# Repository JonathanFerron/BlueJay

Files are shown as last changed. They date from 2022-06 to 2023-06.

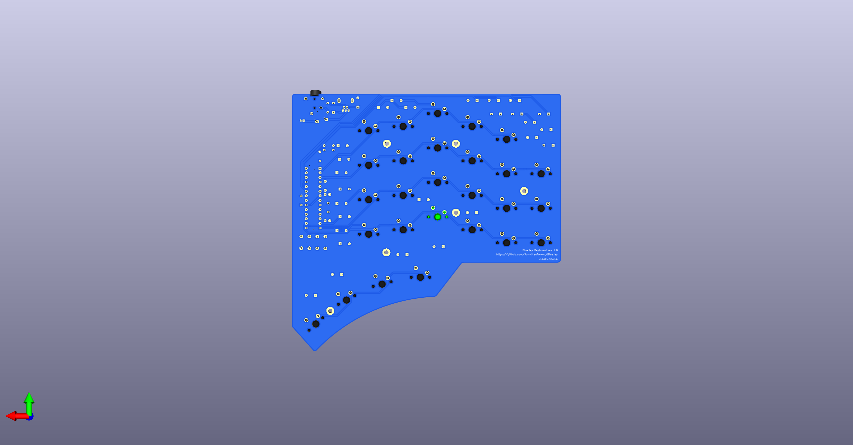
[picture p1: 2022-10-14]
printouts/bluejay_left_3D_back.png

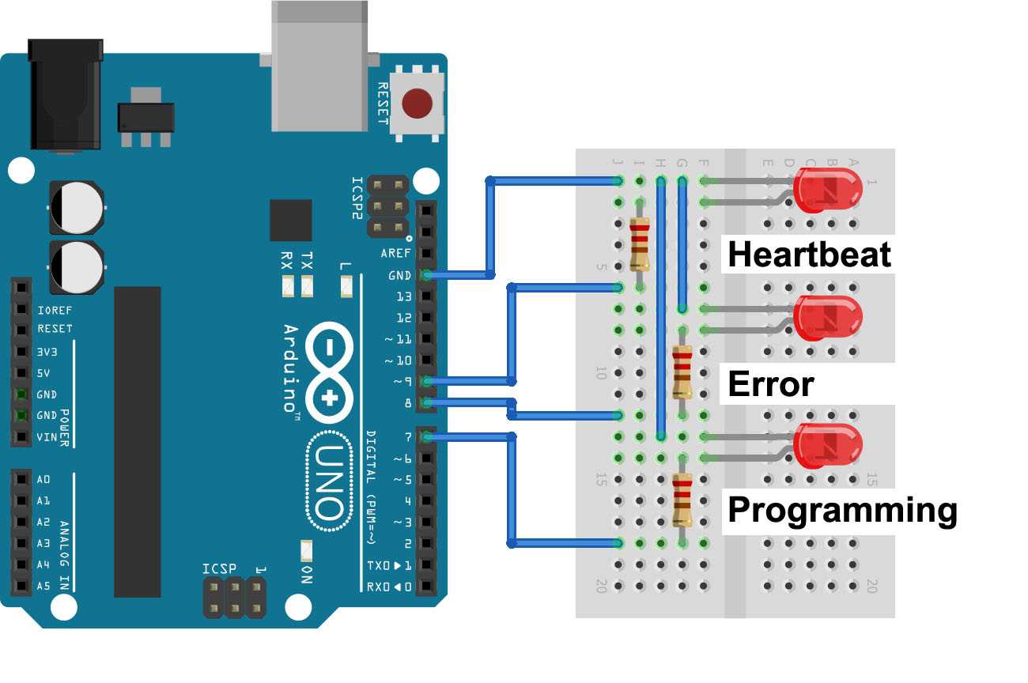
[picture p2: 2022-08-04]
build/Arduino_ISP_LEDSOK.jpg

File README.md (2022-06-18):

# BlueJay
 Split Ergonomic Keyboard

This is a project for a new split ergonomic QMK-powered keyboard. The goal is for it to be minimalist, meant for users who strictly touch-type, and made with easy to solder through-hole components. It is significantly inspired on the [Torn](https://github.com/rtitmuss/torn) split keyboard, with modifications such as adding a partial "numrow" and moving the thumb cluster further out.

Prototype Key Positions

This work is licensed under a
[Creative Commons Attribution-NonCommercial-ShareAlike 4.0 International License][cc-by-nc-sa].

[][cc-by-nc-sa]

[cc-by-nc-sa]: http://creativecommons.org/licenses/by-nc-sa/4.0/
[cc-by-nc-sa-image]: https://licensebuttons.net/l/by-nc-sa/4.0/88x31.png
[cc-by-nc-sa-shield]: https://img.shields.io/badge/License-CC%20BY--NC--SA%204.0-lightgrey.svg

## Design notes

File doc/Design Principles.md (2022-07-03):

# BlueJay54 design principles

- 6 columns, 5 rows in total (of which one is thumb cluster): 5 top row + 3x6 middle + 4 thumb cluster per hand: total of 54 keys
	+ All 1U keys:
	+ 10 x R1 top (number) row
	+ 12 x R2 qwerty row
	+ 10 x R3 home row + 2 R3 homing keys
	+ 12 x R4 bottom row
	+ 8 x R2 thumb keys (get an extra set of 8 R1 keys as well)
	+ = Total 54 keycaps

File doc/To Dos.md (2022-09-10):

# BlueJay54 To Dos

- [ ] Update Gerber Files
- [ ] Check keyboard QMK matrix.c scanning code and create default keymap.c

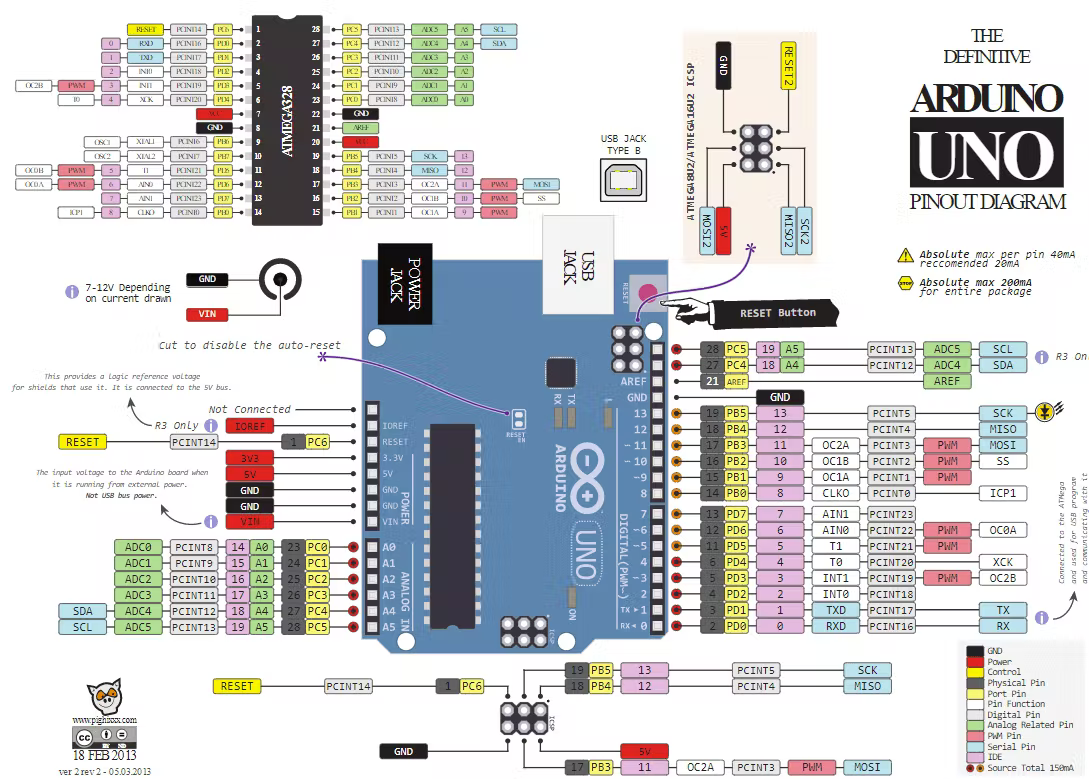
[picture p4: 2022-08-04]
build/arduino uno pinout.png

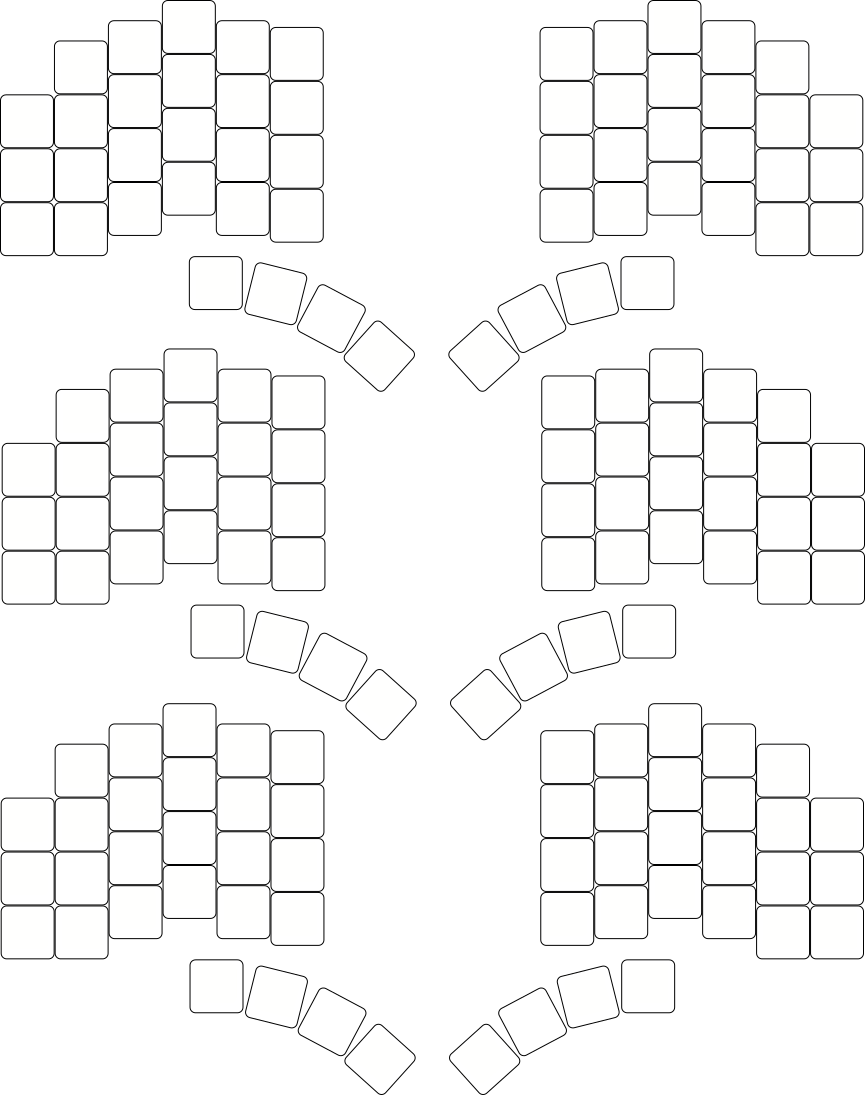
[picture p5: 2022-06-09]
doc/bluejay-prototype-v4---both-hands.png

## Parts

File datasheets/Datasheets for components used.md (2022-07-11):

- [ATMega 328P](https://www.microchip.com/en-us/product/ATmega328P)
- [MCP23017 Datasheet](https://www.microchip.com/en-us/product/mcp23017)
- [SJ-43514](https://www.cuidevices.com/product/resource/sj-4351x.pdf)
- [4.7uF Electrolytic Capacitor ECE-A1EKS4R7](https://industrial.panasonic.com/cdbs/www-data/pdf/RDF0000/ABA0000C1059.pdf)
- [Bourns Resettable Fuse MF-R010](https://www.bourns.com/docs/product-datasheets/mf-r.pdf?sfvrsn=bc732717_46)
- [Molex 548190519 Mini USB receptacle](https://www.molex.com/pdm_docs/sd/548190519_sd.pdf)

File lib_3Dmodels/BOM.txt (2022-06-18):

3DX_CUI_DEVICES_Supplier: CUI Devices
3DX_CUI_DEVICES_Description: 3.5 mm, Stereo, Right Angle, Through Hole, 4 Conductors, 0 Internal Switches, Audio Jack Connector
3DX_CUI_DEVICES_Model Number: SJ-43514

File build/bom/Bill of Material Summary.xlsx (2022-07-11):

Ref | Qnty | Value | Description
C1, C2 | 2 | 22p | Unpolarized ceramic capacitor
C3, C6 | 2 | 4.7u | Polarized Eloctrolytic cap, ECE-A1EKS4R7
C4, C5, C7 | 3 | 100n | Unpolarized ceramic capacitor
Da1-Df4 | 54 | 1N4148 | DO-35 Diode
DZ1, DZ2 | 2 | 3.6V | DO-35 Zener diode, 3.6V, BZX79-C3V6
F1, | 1 | 100mA | Bourns Resettable Fuse MF-R010
J1-J2 | 2 | SJ-43514
PB1-PB2 | 2 | BOOT, RESET | APEM MJTP1230
R1 | 1 | 1.5k | 5% 1/6W
R2, R3 | 2 | 75R | 5% 1/6W
R4 | 1 | 10k | 1/6W 1%?
R5, R6 | 2 | 2.2k | 1/6W 1%?
U1 | 1 | ATmega328P-PU | ATmega328P-PU
U2 | 1 | MCP23017 | MCP23017-E/SP
USB1 | 1 | USB_B_Mini | Molex 0548190519 Mini USB receptacle
Y1 | 1 | 16MHz | Crystal 16MHz, TXC, 9B-16.000MEEJ-B
 | 2 |  | DIP-28_W7.62mm_Socket, Socket 28 Position 2.54mm Solder Straight Through Hole Dual Wipe, IC Socket, DIP, 28
SWa1-SWf4 | 54 |  | Cherry Mount Key Switches
clip: grabber / hook
breadboard wires kit
10 uF cap for initial programming of MCU
switch puller
M2 screws (3mm 30 pcs, 5mm 6 pcs)
M2 standoffs (3mm 12 pcs, 8mm 6 pcs)
M2 standoffs (3mm+3mm 18 pcs)

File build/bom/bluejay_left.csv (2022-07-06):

Source: | C:\Users\Jonathan\Documents\ergo kb\BlueJay\github\BlueJay\pcb_left\bluejay_left.kicad_sch
Date: | 2022-07-06 9:00:13 AM
Tool: | Eeschema (6.0.5)
Generator: | C:\Program Files\KiCad\6.0\bin\scripting\plugins/bom_csv_grouped_by_value_with_fp.py
Component Count: | 72
Ref | Qnty | Value | Cmp name | Footprint | Description | Vendor
C1, C2, | 2 | 22p | C_Small | BlueJay footprints:C_Disc_D3.0mm_W1.6mm_P2.50mm | Unpolarized capacitor, small symbol
C3, | 1 | 4.7u | Device_CP1_Small | BlueJay footprints:CP_Radial_D4.0mm_P1.50mm
C4, C5, | 2 | 100n | C_Small | BlueJay footprints:C_Disc_D4.3mm_W1.9mm_P5.00mm | Unpolarized capacitor, small symbol
Da1, Da2, Da3, Da4, Da5, | 5 | 1N4148 | 1N4148 | BlueJay footprints:D_DO-35_SOD27_P5.08mm_Horizontal | DO-35 Diode, Small Signal, Fast Switching, 75V, 150mA, 4ns, Alternate KiCad Library
Db1, Db2, Db3, Db4, Db5, | 5 | 1N4148 | 1N4148 | BlueJay footprints:D_DO-35_SOD27_P5.08mm_Horizontal | DO-35 Diode, Small Signal, Fast Switching, 75V, 150mA, 4ns, Alternate KiCad Library
Dc1, Dc2, Dc3, Dc4, Dc5, | 5 | 1N4148 | 1N4148 | BlueJay footprints:D_DO-35_SOD27_P5.08mm_Horizontal | DO-35 Diode, Small Signal, Fast Switching, 75V, 150mA, 4ns, Alternate KiCad Library
Dd1, Dd2, Dd3, Dd4, Dd5, | 5 | 1N4148 | 1N4148 | BlueJay footprints:D_DO-35_SOD27_P5.08mm_Horizontal | DO-35 Diode, Small Signal, Fast Switching, 75V, 150mA, 4ns, Alternate KiCad Library
De1, De2, De3, De4, | 4 | 1N4148 | 1N4148 | BlueJay footprints:D_DO-35_SOD27_P5.08mm_Horizontal | DO-35 Diode, Small Signal, Fast Switching, 75V, 150mA, 4ns, Alternate KiCad Library
Df2, Df3, Df4, | 3 | 1N4148 | 1N4148 | BlueJay footprints:D_DO-35_SOD27_P5.08mm_Horizontal | DO-35 Diode, Small Signal, Fast Switching, 75V, 150mA, 4ns, Alternate KiCad Library
DZ1, DZ2, | 2 | 3.6V | BZX79-C3V6 | BlueJay footprints:D_DO-35_SOD27_P5.08mm_Horizontal | DO-35 Zener diode, 3.6V, 400mW, Alternate KiCAD Library
F1, | 1 | 100mA | Device_Polyfuse_Small | BlueJay footprints:polyfuse_5.1mm
J1, | 1 | SJ-43514 | SJ-43514 | BlueJay footprints:CUI_SJ-43514
PB1, | 1 | RESET | Switch_SW_Push | BlueJay footprints:SW_PUSH_6mm
PB2, | 1 | BOOT | Switch_SW_Push | BlueJay footprints:SW_PUSH_6mm
R1, | 1 | 1.5k | Device_R_Small | BlueJay footprints:R_Axial_DIN0204_L3.6mm_D1.6mm_P5.08mm_Horizontal
R2, R3, | 2 | 75R | Device_R_Small | BlueJay footprints:R_Axial_DIN0204_L3.6mm_D1.6mm_P5.08mm_Horizontal
R4, | 1 | 10k | Device_R_Small | BlueJay footprints:R_Axial_DIN0204_L3.6mm_D1.6mm_P5.08mm_Horizontal
SWa1, SWa2, SWa3, SWa4, SWa5, | 5 | KEYSW | Switch_SW_Push | Switch_Keyboard_Cherry_MX:SW_Cherry_MX_PCB_1.00u
SWb1, SWb2, SWb3, SWb4, SWb5, | 5 | KEYSW | Switch_SW_Push | Switch_Keyboard_Cherry_MX:SW_Cherry_MX_PCB_1.00u
SWc1, SWc2, SWc3, SWc4, SWc5, | 5 | KEYSW | Switch_SW_Push | Switch_Keyboard_Cherry_MX:SW_Cherry_MX_PCB_1.00u
SWd1, SWd2, SWd3, SWd4, SWd5, | 5 | KEYSW | Switch_SW_Push | Switch_Keyboard_Cherry_MX:SW_Cherry_MX_PCB_1.00u
SWe1, SWe2, SWe3, SWe4, | 4 | KEYSW | Switch_SW_Push | Switch_Keyboard_Cherry_MX:SW_Cherry_MX_PCB_1.00u
SWf2, SWf3, SWf4, | 3 | KEYSW | Switch_SW_Push | Switch_Keyboard_Cherry_MX:SW_Cherry_MX_PCB_1.00u
U1, | 1 | ATmega328P-PU | ATmega328P-PU | Package_DIP_AKL:DIP-28_W7.62mm_Socket
USB1, | 1 | USB_B_Mini | 0548190519 | BlueJay footprints:USB_Mini_B_Female_548190519 | CONN RCPT USB2.0 MINI B 5P R/A
Y1, | 1 | 16MHz | Device_Crystal_Small | BlueJay footprints:Crystal_HC49-4H_Vertical

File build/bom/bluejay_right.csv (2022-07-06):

Source: | C:\Users\Jonathan\Documents\ergo kb\BlueJay\github\BlueJay\pcb_right\bluejay_right.kicad_sch
Date: | 2022-07-06 9:00:43 AM
Tool: | Eeschema (6.0.5)
Generator: | C:\Program Files\KiCad\6.0\bin\scripting\plugins/bom_csv_grouped_by_value_with_fp.py
Component Count: | 60
Ref | Qnty | Value | Cmp name | Footprint | Description | Vendor
C6, | 1 | 4.7u | Device_CP1_Small | BlueJay footprints:CP_Radial_D4.0mm_P1.50mm
C7, | 1 | 100n | C_Small | BlueJay footprints:C_Disc_D4.3mm_W1.9mm_P5.00mm | Unpolarized capacitor, small symbol
Da1, Da2, Da3, Da4, Da5, | 5 | 1N4148 | 1N4148 | BlueJay footprints:D_DO-35_SOD27_P5.08mm_Horizontal | DO-35 Diode, Small Signal, Fast Switching, 75V, 150mA, 4ns, Alternate KiCad Library
Db1, Db2, Db3, Db4, Db5, | 5 | 1N4148 | 1N4148 | BlueJay footprints:D_DO-35_SOD27_P5.08mm_Horizontal | DO-35 Diode, Small Signal, Fast Switching, 75V, 150mA, 4ns, Alternate KiCad Library
Dc1, Dc2, Dc3, Dc4, Dc5, | 5 | 1N4148 | 1N4148 | BlueJay footprints:D_DO-35_SOD27_P5.08mm_Horizontal | DO-35 Diode, Small Signal, Fast Switching, 75V, 150mA, 4ns, Alternate KiCad Library
Dd1, Dd2, Dd3, Dd4, Dd5, | 5 | 1N4148 | 1N4148 | BlueJay footprints:D_DO-35_SOD27_P5.08mm_Horizontal | DO-35 Diode, Small Signal, Fast Switching, 75V, 150mA, 4ns, Alternate KiCad Library
De1, De2, De3, De4, | 4 | 1N4148 | 1N4148 | BlueJay footprints:D_DO-35_SOD27_P5.08mm_Horizontal | DO-35 Diode, Small Signal, Fast Switching, 75V, 150mA, 4ns, Alternate KiCad Library
Df2, Df3, Df4, | 3 | 1N4148 | 1N4148 | BlueJay footprints:D_DO-35_SOD27_P5.08mm_Horizontal | DO-35 Diode, Small Signal, Fast Switching, 75V, 150mA, 4ns, Alternate KiCad Library
J2, | 1 | SJ-43514 | SJ-43514 | BlueJay footprints:CUI_SJ-43514
R5, R6, | 2 | 2.2k | Device_R_Small | BlueJay footprints:R_Axial_DIN0204_L3.6mm_D1.6mm_P5.08mm_Horizontal
SWa1, SWa2, SWa3, SWa4, SWa5, | 5 | KEYSW | Switch_SW_Push | BlueJay footprints:SW_MX
SWb1, SWb2, SWb3, SWb4, SWb5, | 5 | KEYSW | Switch_SW_Push | BlueJay footprints:SW_MX
SWc1, SWc2, SWc3, SWc4, SWc5, | 5 | KEYSW | Switch_SW_Push | BlueJay footprints:SW_MX
SWd1, SWd2, SWd3, SWd4, SWd5, | 5 | KEYSW | Switch_SW_Push | BlueJay footprints:SW_MX
SWe1, SWe2, SWe3, SWe4, | 4 | KEYSW | Switch_SW_Push | BlueJay footprints:SW_MX
SWf2, SWf3, SWf4, | 3 | KEYSW | Switch_SW_Push | BlueJay footprints:SW_MX
U2, | 1 | MCP23017 | Interface_Expansion_MCP23017_SP | Package_DIP_AKL:DIP-28_W7.62mm_Socket

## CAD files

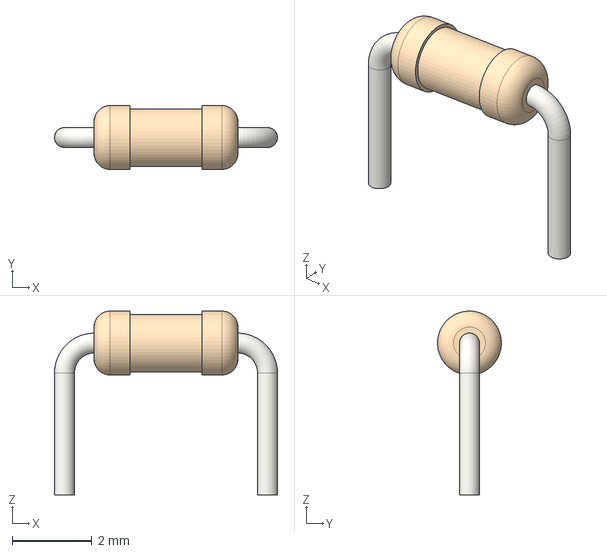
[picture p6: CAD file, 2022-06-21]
lib_3Dmodels/R_Axial_DIN0204_L3.6mm_D1.6mm_P5.08mm_Horizontal.step
5.58 x 1.60 x 4.60 mm

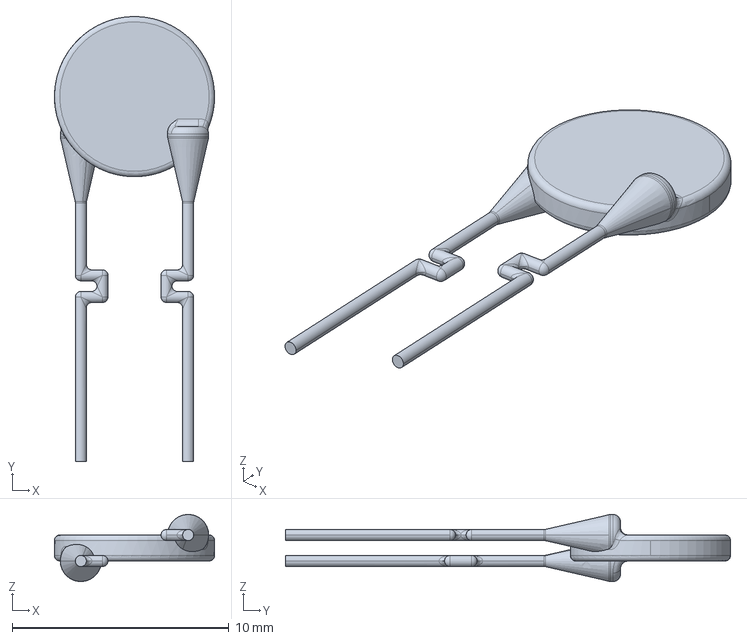
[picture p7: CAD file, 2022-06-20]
lib_3Dmodels/MF-R010.stp
7.40 x 20.6 x 3.10 mm

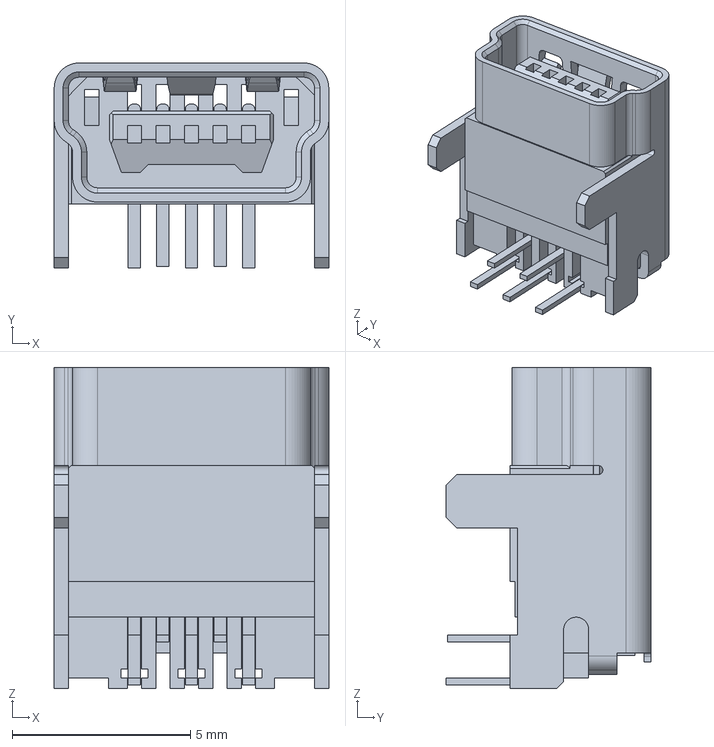
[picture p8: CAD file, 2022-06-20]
lib_3Dmodels/usb mini b connector 54819-0519.stp
7.70 x 5.75 x 9.00 mm

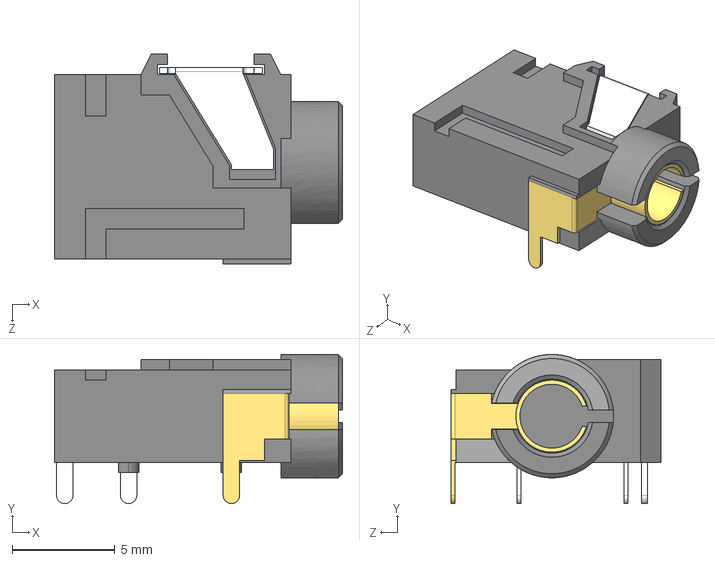
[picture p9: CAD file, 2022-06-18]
lib_3Dmodels/CUI_DEVICES_SJ-43514.igs
14.0 x 7.25 x 10.2 mm

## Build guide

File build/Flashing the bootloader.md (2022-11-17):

Flashing the bootloader

Arduino Uno as ISP
- Lead ArduinoISP sketch (from file -> examples)
- tools -> board -> Arduino Uno
- tools -> port -> COM6 (Arduino Uno)
- compile
- verify
- upload sketch to Uno (programmer)

Wiring the programmer
Use an Arduino Uno to program the AtMega328P on a breadboard. You need to connect the following pins. See pinout diagrams for the ISP header on the Arduino Uno and the ATMega328P pinout diagram.

Arduino Uno 				Target ATMega328P
ISP Pin 1 - MISO 		Pin 18 - MISO
ISP Pin 2 - +Vcc 		Pin 7 and 20 - +5V
ISP Pin 3 - SCK 		Pin 19 - SCK
ISP Pin 4 - MOSI 		Pin 17 - MOSI
ISP Pin 6 - Gnd 		Pin 8 and 22 - GND
Digital Pin 10 			Pin 1 - Reset

The Arduino Uno board needs a 10µF electrolytic capacitor connected to RESET and GND with the positive (long leg) connected to RESET. The capacitor has to be placed after the programmer board has been loaded with the ISP sketch.

Downloading the bootloader
Download the USBaspLoader source code from https://github.com/rtitmuss/USBaspLoader/tree/torn. This can be done directly from Git Hub Desktop.

Flashing

You may need to change the port to your Arduino in the Makefile.inc. Replace the path in line 41 /dev/cu.usbmodem* with your own. I used com6 under windows 10.

41:     PROGRAMMER = -c avrisp -P com6 -b19200

Make sure to save your changes before continuing.

Open a QMK MSYS terminal and navigate to your USBaspLoader (bluejay branch) folder and  at that location. Flash the bootloader using:

    make
    make flash
    make fuse

Once the bootloader has been flashed to the board, disconnect the Arduino Uno.

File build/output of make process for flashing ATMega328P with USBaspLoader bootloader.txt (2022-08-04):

[Jonathan@DeskMini-JF-LM USBaspLoader]$ make
.
.
======>BUILDING BOOTLOADER FIRMWARE
.
make[1]: Entering directory '/c/Users/Jonathan/Documents/ergo kb/USBaspLoader/firmware'
main.c: In function 'main':
<built-in>: warning: function declared 'noreturn' has a 'return' statement
.
.
.
!!!ATTANTION!!!
(data+text) MUST fit into your MCUs bootloader section
.
   text    data     bss     dec     hex filename
   2178       6      55    2239     8bf main.elf
.
.
.
make[1]: Leaving directory '/c/Users/Jonathan/Documents/ergo kb/USBaspLoader/firmware'
.
.
======>BUILDING BOOTLOADER UPDATER (EXPERIMENTAL)
.
make[1]: Entering directory '/c/Users/Jonathan/Documents/ergo kb/USBaspLoader/updater'
In file included from updater.c:8:
usbasploader.h:20:14: warning: duplicate 'const' declaration specifier [-Wduplicate-decl-specifier]
 extern const const uint16_t usbasploader[SIZEOF_new_firmware>>1] PROGMEM;
              ^~~~~
updater.c:53:4: warning: #warning I do not know where new "bootloader__do_spm" is located - assuming "NEW_BOOTLOADER_ADDRESS+(funcaddr___bootloader__do_spm % SPM_PAGESIZE)" [-Wcpp]
   #warning I do not know where new "bootloader__do_spm" is located - assuming "NEW_BOOTLOADER_ADDRESS+(funcaddr___bootloader__do_spm % SPM_PAGESIZE)"
    ^~~~~~~
updater.c:61:4: warning: #warning "TEMP_SPM_PAGEADR" is not defined explicitly - will choose END OF FLASH ! [-Wcpp]
   #warning "TEMP_SPM_PAGEADR" is not defined explicitly - will choose END OF FLASH !
    ^~~~~~~
.
.
   text    data     bss     dec     hex filename
   3170       2       0    3172     c64 updater.elf
.
make[1]: Leaving directory '/c/Users/Jonathan/Documents/ergo kb/USBaspLoader/updater'

[Jonathan@DeskMini-JF-LM USBaspLoader]$ make flash
.
.
======>BUILDING BOOTLOADER FIRMWARE
.
make[1]: Entering directory '/c/Users/Jonathan/Documents/ergo kb/USBaspLoader/firmware'
make[1]: Nothing to be done for 'all'.
make[1]: Leaving directory '/c/Users/Jonathan/Documents/ergo kb/USBaspLoader/firmware'
make[1]: Entering directory '/c/Users/Jonathan/Documents/ergo kb/USBaspLoader/firmware'
.
avrdude -c avrisp -P com6 -b19200 -p atmega328p -U flash:w:main.hex:i

avrdude.exe: AVR device initialized and ready to accept instructions

Reading | ################################################## | 100% 0.03s

avrdude.exe: Device signature = 0x1e950f (probably m328p)
avrdude.exe: NOTE: "flash" memory has been specified, an erase cycle will be performed
             To disable this feature, specify the -D option.
avrdude.exe: erasing chip
avrdude.exe: reading input file "main.hex"
avrdude.exe: writing flash (30856 bytes):

Writing | ################################################## | 100% 0.06s

avrdude.exe: 30856 bytes of flash written
avrdude.exe: verifying flash memory against main.hex:
avrdude.exe: load data flash data from input file main.hex:
avrdude.exe: input file main.hex contains 30856 bytes
avrdude.exe: reading on-chip flash data:

Reading | ################################################## | 100% 0.06s

avrdude.exe: verifying ...
avrdude.exe: 30856 bytes of flash verified

avrdude.exe: safemode: Fuses OK (E:FF, H:D9, L:62)

avrdude.exe done.  Thank you.

.
.
make[1]: Leaving directory '/c/Users/Jonathan/Documents/ergo kb/USBaspLoader/firmware'

[Jonathan@DeskMini-JF-LM USBaspLoader]$ make fuse
.
.
======>BUILDING BOOTLOADER FIRMWARE
.
make[1]: Entering directory '/c/Users/Jonathan/Documents/ergo kb/USBaspLoader/firmware'
make[1]: Nothing to be done for 'all'.
make[1]: Leaving directory '/c/Users/Jonathan/Documents/ergo kb/USBaspLoader/firmware'
make[1]: Entering directory '/c/Users/Jonathan/Documents/ergo kb/USBaspLoader/firmware'
.
avrdude -c avrisp -P com6 -b19200 -p atmega328p -U lfuse:w:0xd7:m -U hfuse:w:0xd0:m -U efuse:w:0xfc:m

avrdude.exe: AVR device initialized and ready to accept instructions

Reading | ################################################## | 100% 0.03s

avrdude.exe: Device signature = 0x1e950f (probably m328p)
avrdude.exe: reading input file "0xd7"
avrdude.exe: writing lfuse (1 bytes):

Writing | ################################################## | 100% 0.02s

avrdude.exe: 1 bytes of lfuse written
avrdude.exe: verifying lfuse memory against 0xd7:
avrdude.exe: load data lfuse data from input file 0xd7:
avrdude.exe: input file 0xd7 contains 1 bytes
avrdude.exe: reading on-chip lfuse data:

Reading | ################################################## | 100% 0.01s

avrdude.exe: verifying ...
avrdude.exe: 1 bytes of lfuse verified
avrdude.exe: reading input file "0xd0"
avrdude.exe: writing hfuse (1 bytes):

Writing | ################################################## | 100% 0.03s

avrdude.exe: 1 bytes of hfuse written
avrdude.exe: verifying hfuse memory against 0xd0:
avrdude.exe: load data hfuse data from input file 0xd0:
avrdude.exe: input file 0xd0 contains 1 bytes
avrdude.exe: reading on-chip hfuse data:

Reading | ################################################## | 100% 0.01s

avrdude.exe: verifying ...
avrdude.exe: 1 bytes of hfuse verified
avrdude.exe: reading input file "0xfc"
avrdude.exe: writing efuse (1 bytes):

Writing | ################################################## | 100% 0.03s

avrdude.exe: 1 bytes of efuse written
avrdude.exe: verifying efuse memory against 0xfc:
avrdude.exe: load data efuse data from input file 0xfc:
avrdude.exe: input file 0xfc contains 1 bytes
avrdude.exe: reading on-chip efuse data:

Reading | ################################################## | 100% 0.01s

avrdude.exe: verifying ...
avrdude.exe: 1 bytes of efuse verified

avrdude.exe: safemode: Fuses OK (E:FC, H:D0, L:D7)

avrdude.exe done.  Thank you.

.
.
make[1]: Leaving directory '/c/Users/Jonathan/Documents/ergo kb/USBaspLoader/firmware'
[Jonathan@DeskMini-JF-LM USBaspLoader]$

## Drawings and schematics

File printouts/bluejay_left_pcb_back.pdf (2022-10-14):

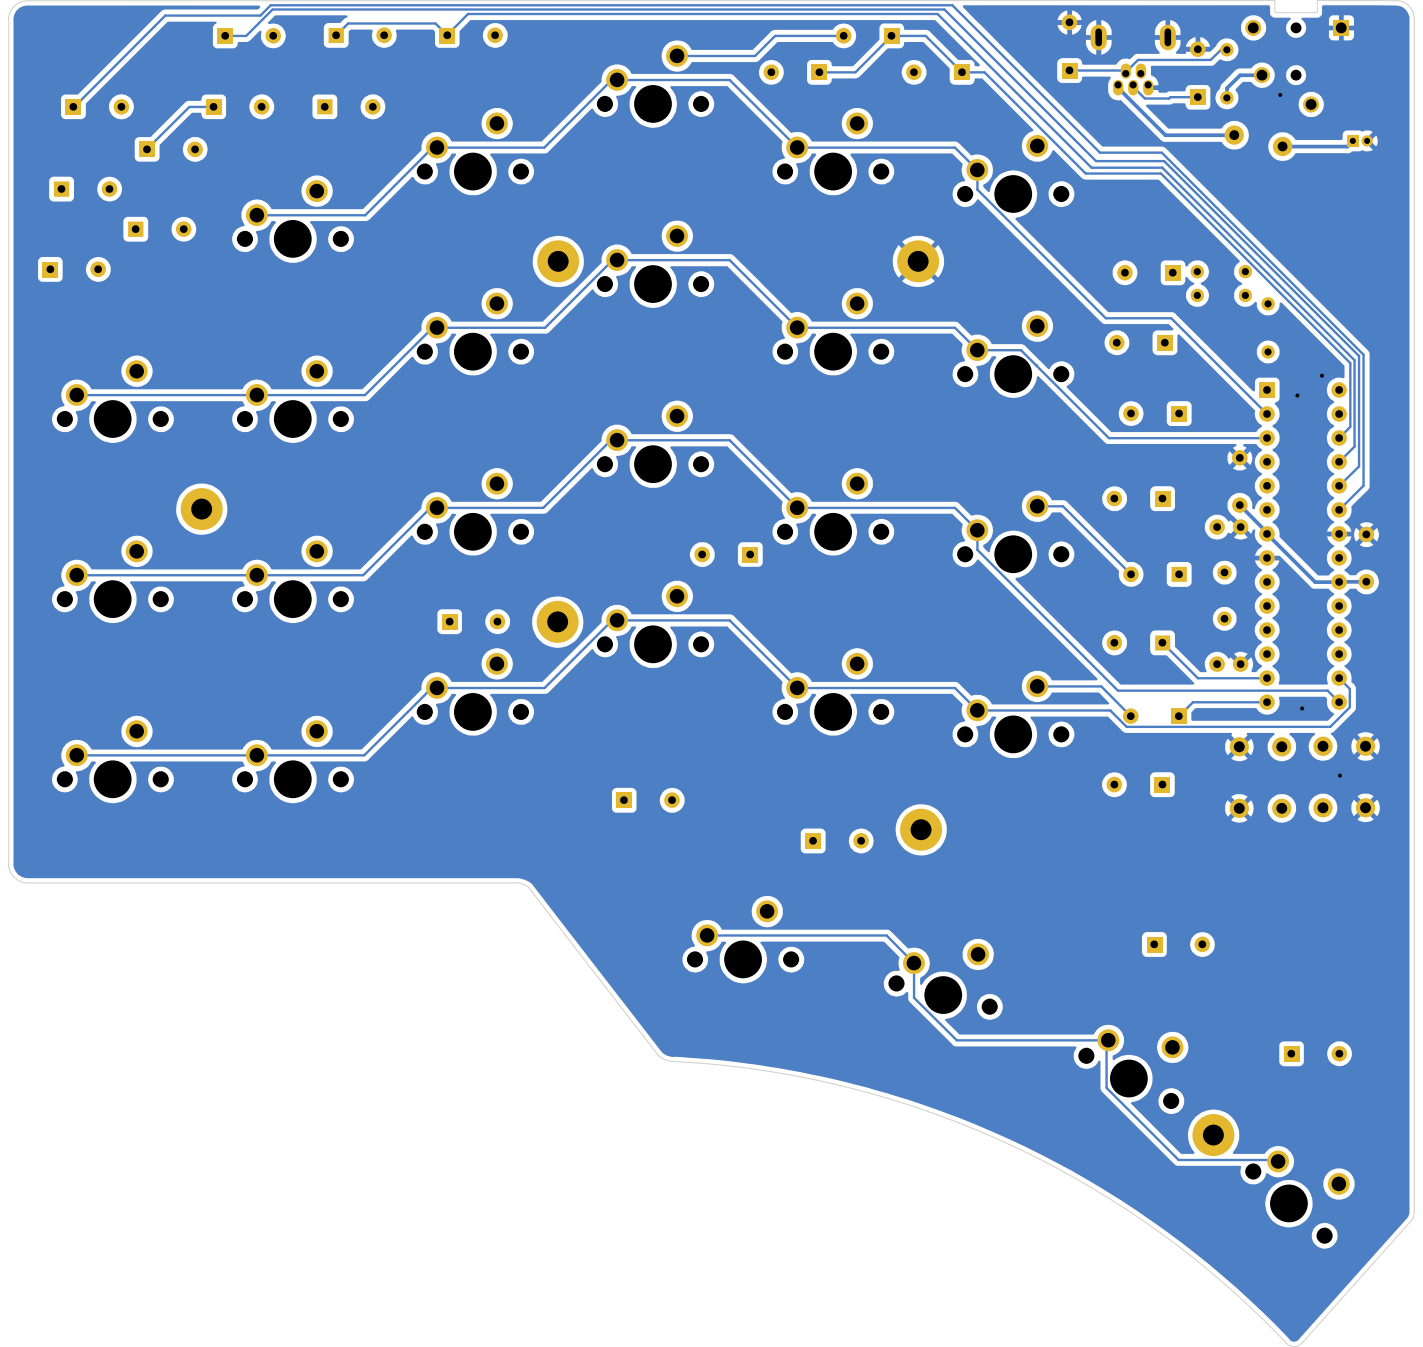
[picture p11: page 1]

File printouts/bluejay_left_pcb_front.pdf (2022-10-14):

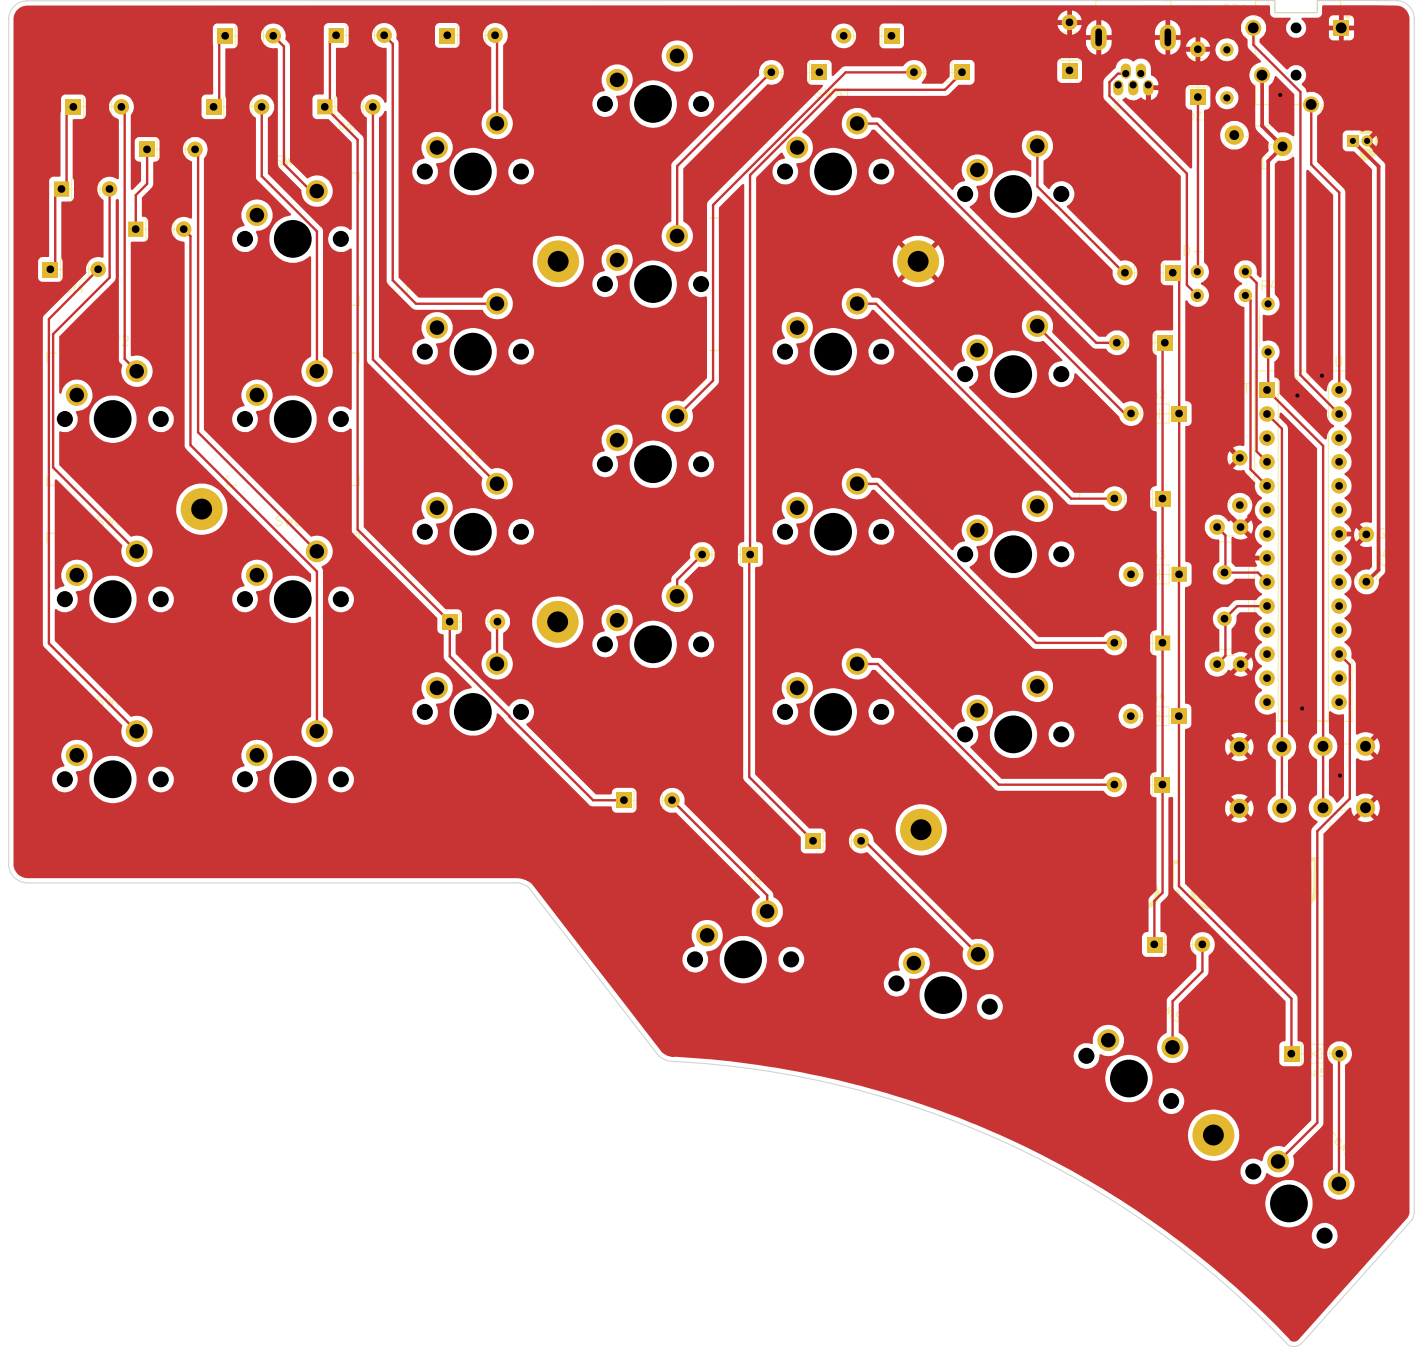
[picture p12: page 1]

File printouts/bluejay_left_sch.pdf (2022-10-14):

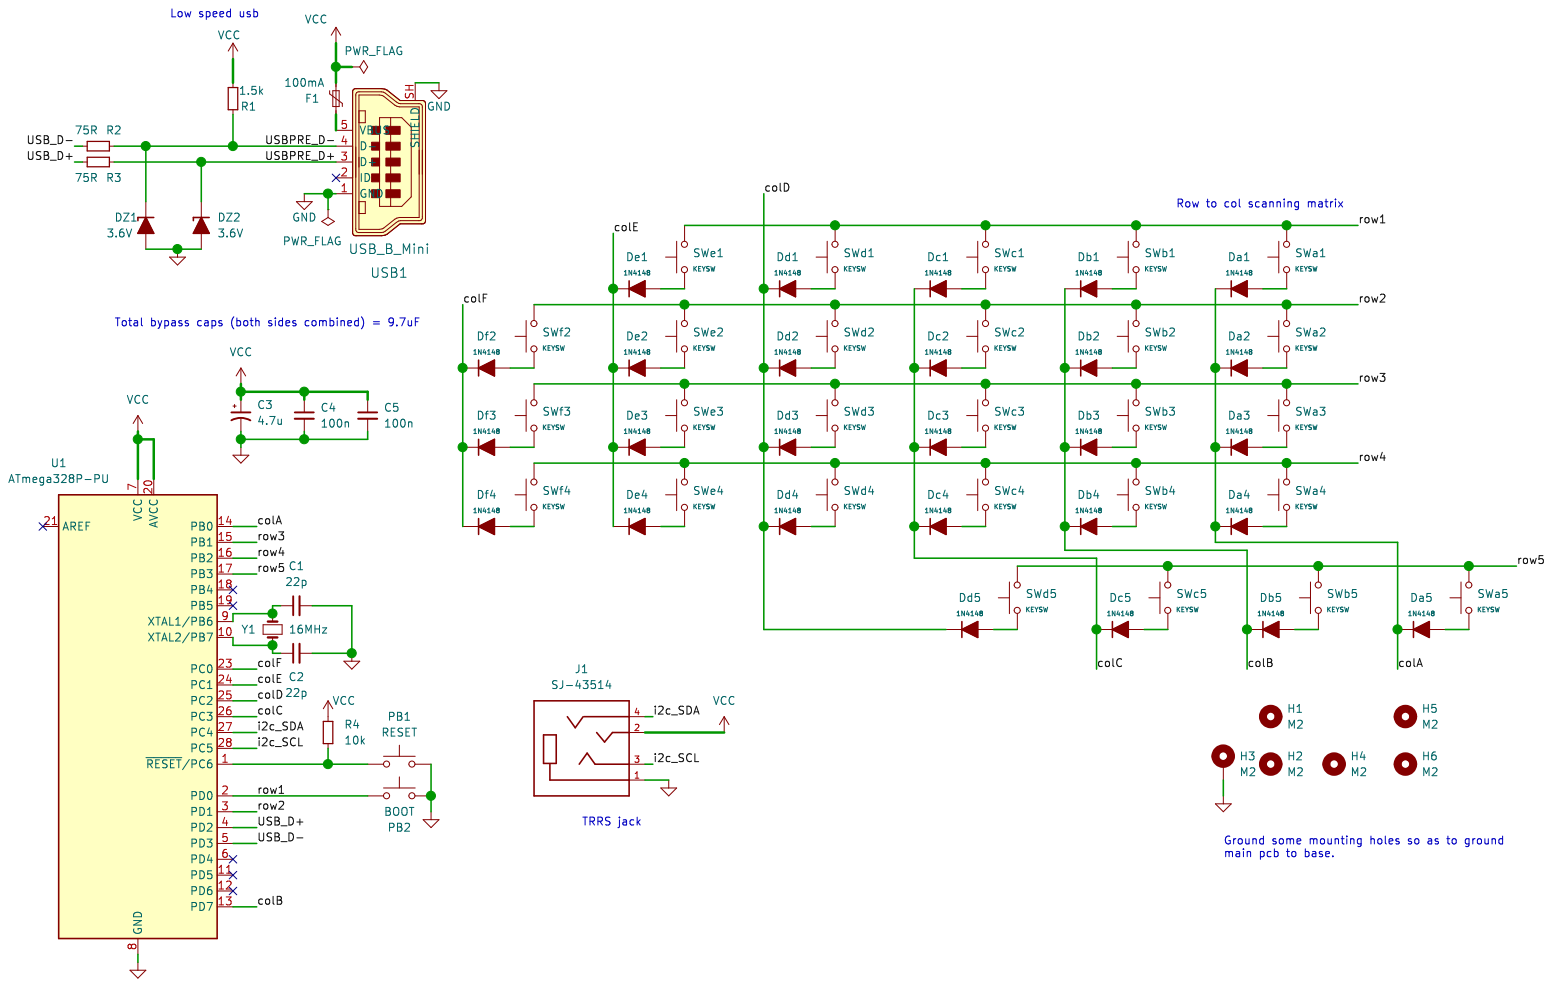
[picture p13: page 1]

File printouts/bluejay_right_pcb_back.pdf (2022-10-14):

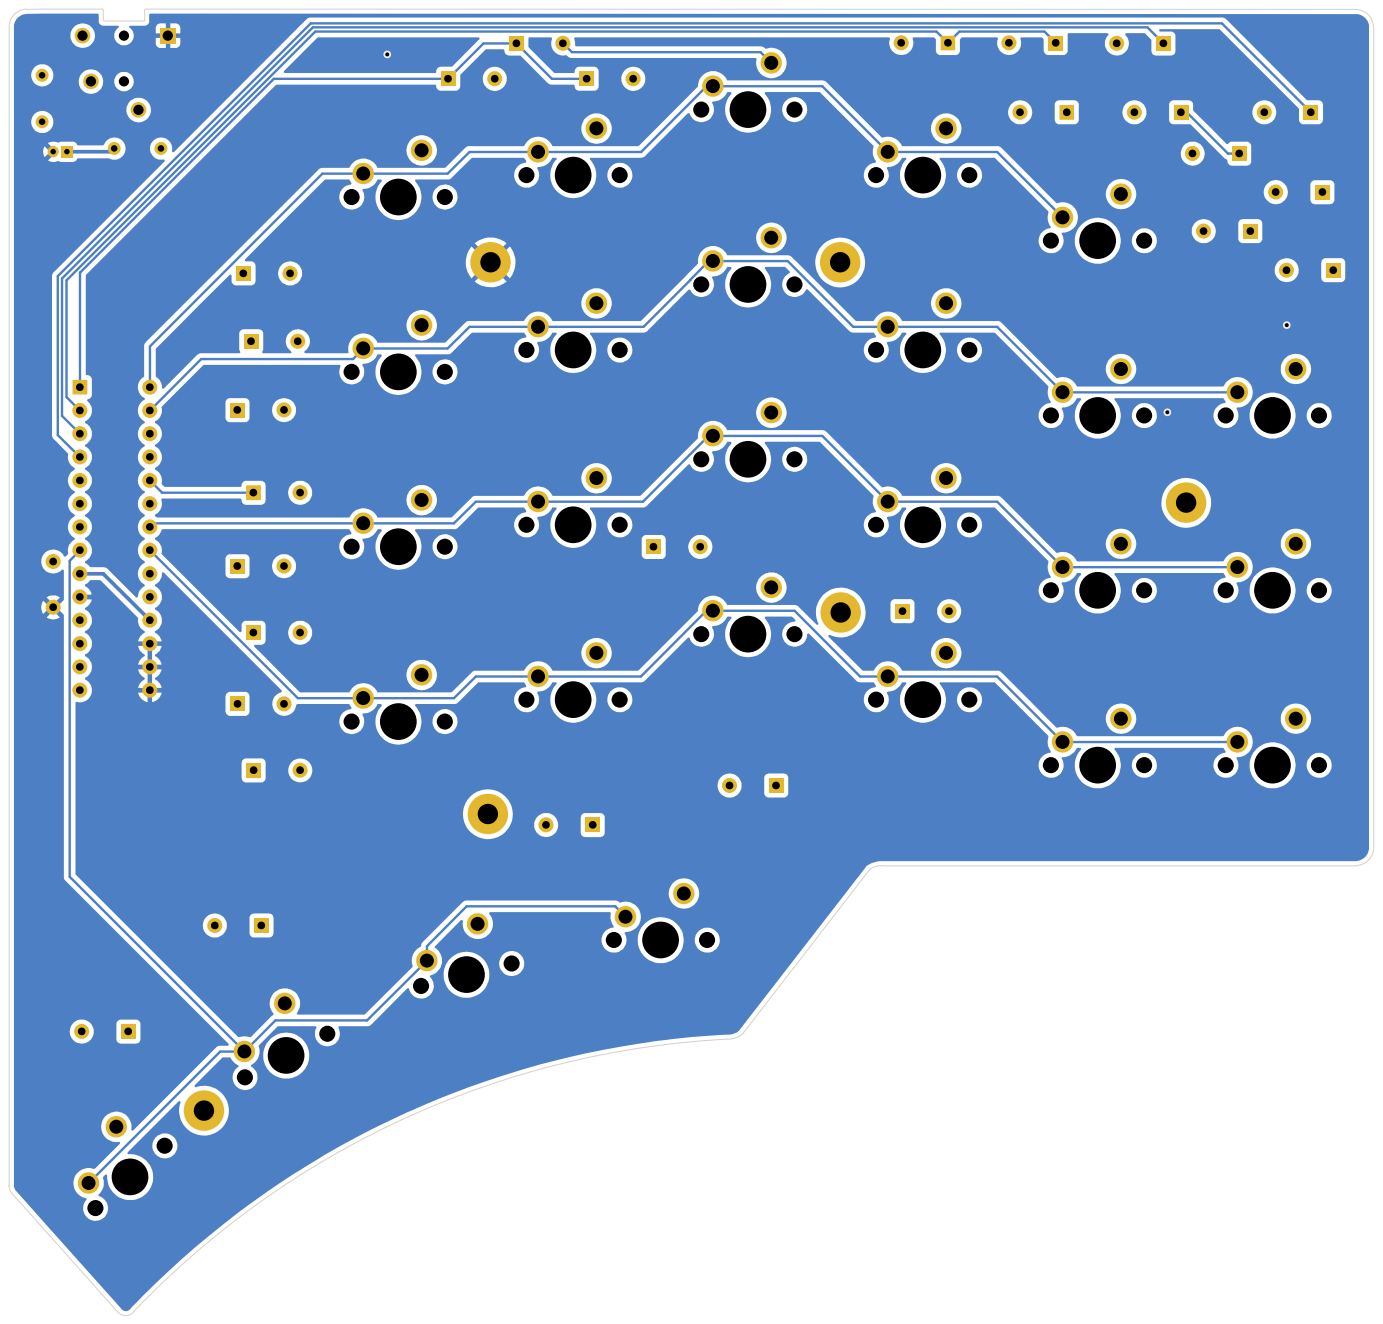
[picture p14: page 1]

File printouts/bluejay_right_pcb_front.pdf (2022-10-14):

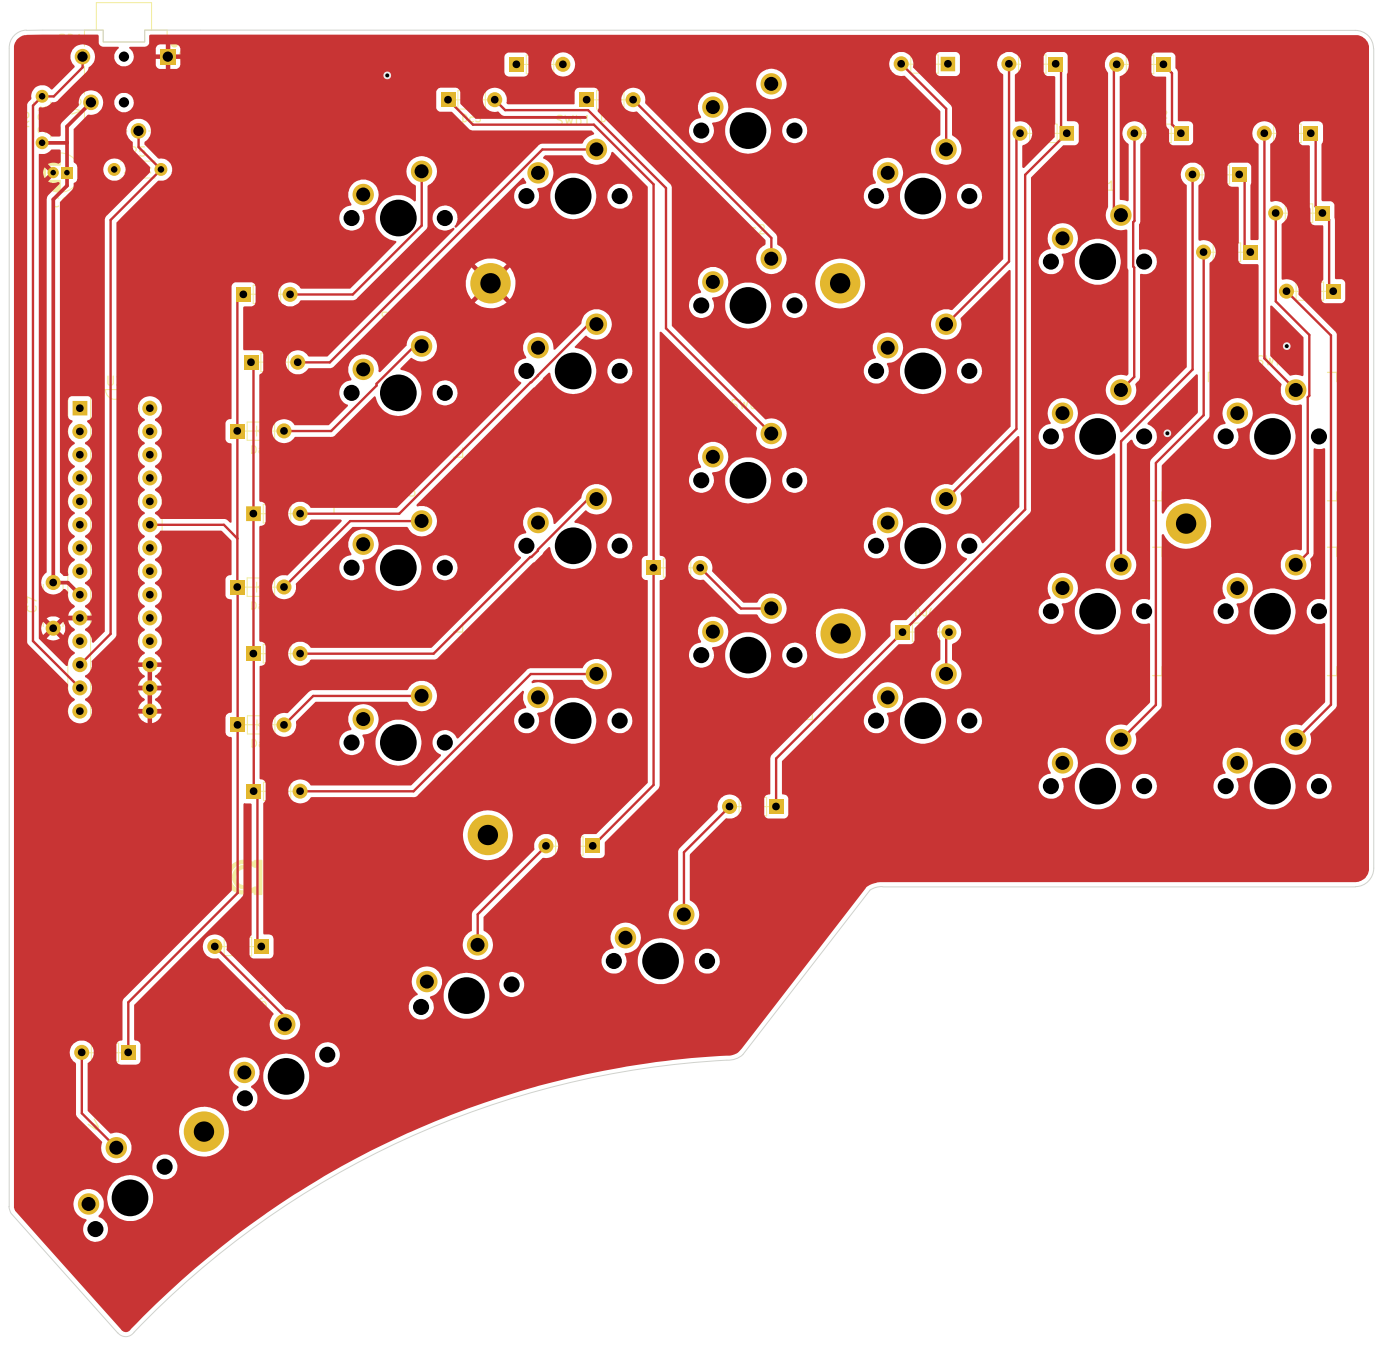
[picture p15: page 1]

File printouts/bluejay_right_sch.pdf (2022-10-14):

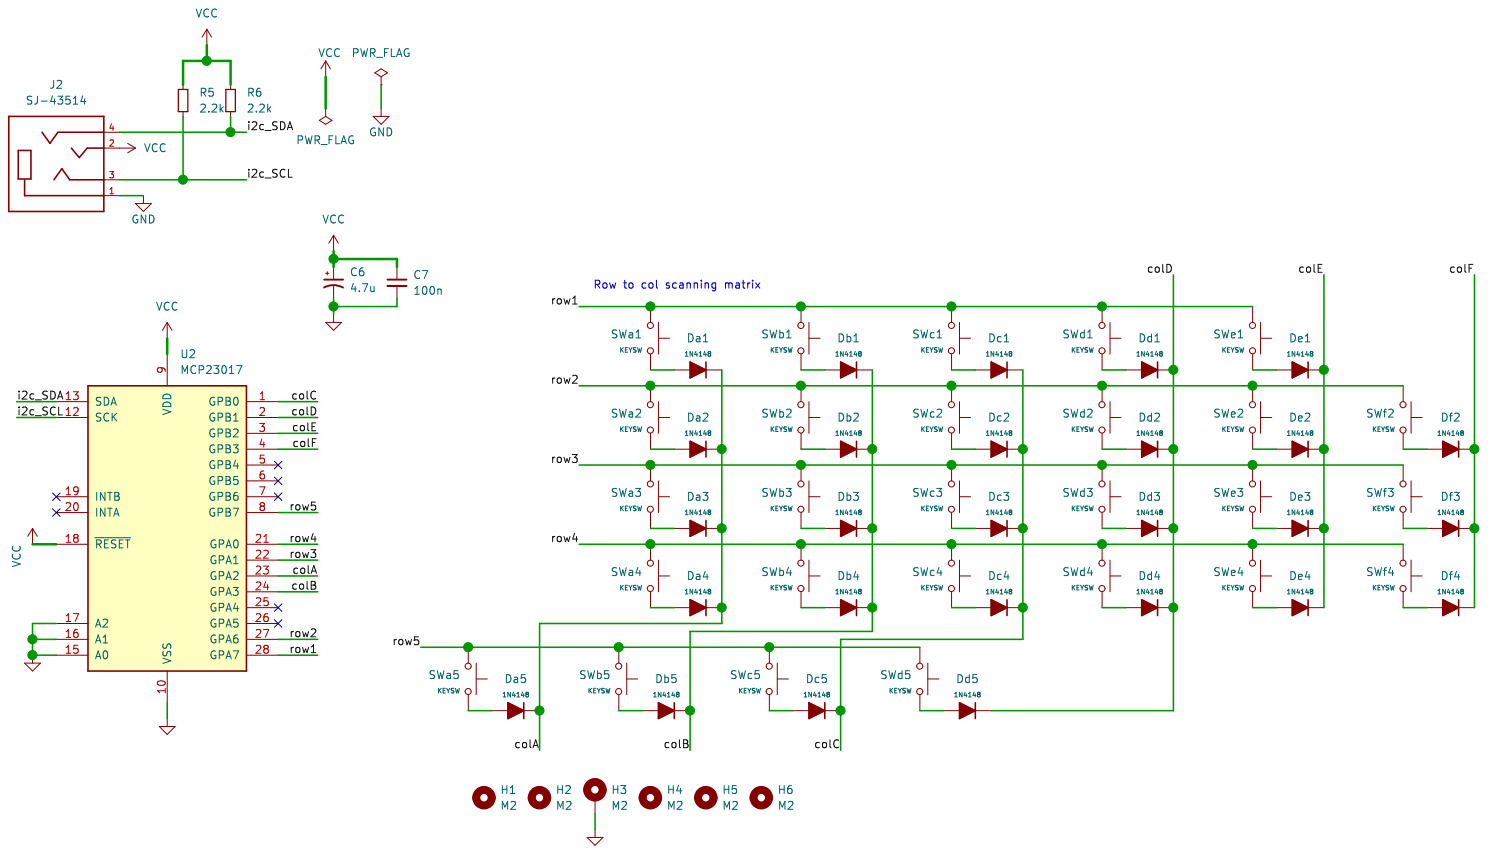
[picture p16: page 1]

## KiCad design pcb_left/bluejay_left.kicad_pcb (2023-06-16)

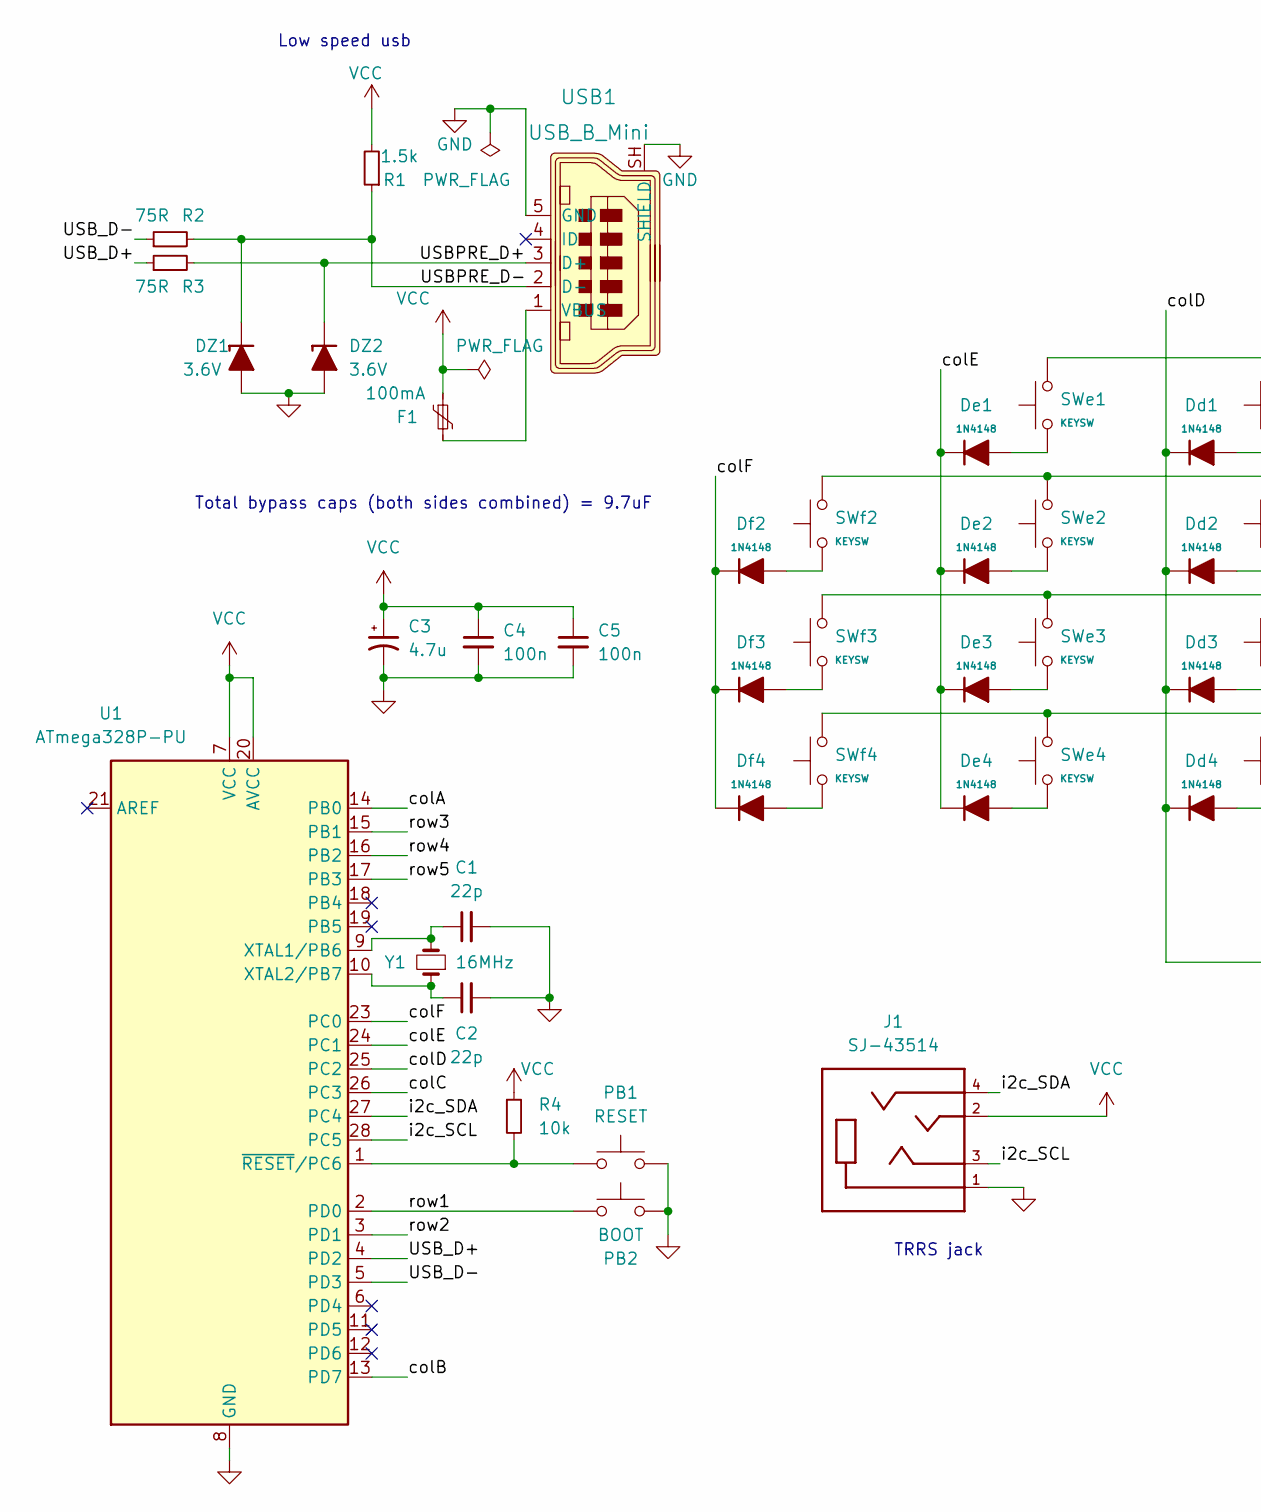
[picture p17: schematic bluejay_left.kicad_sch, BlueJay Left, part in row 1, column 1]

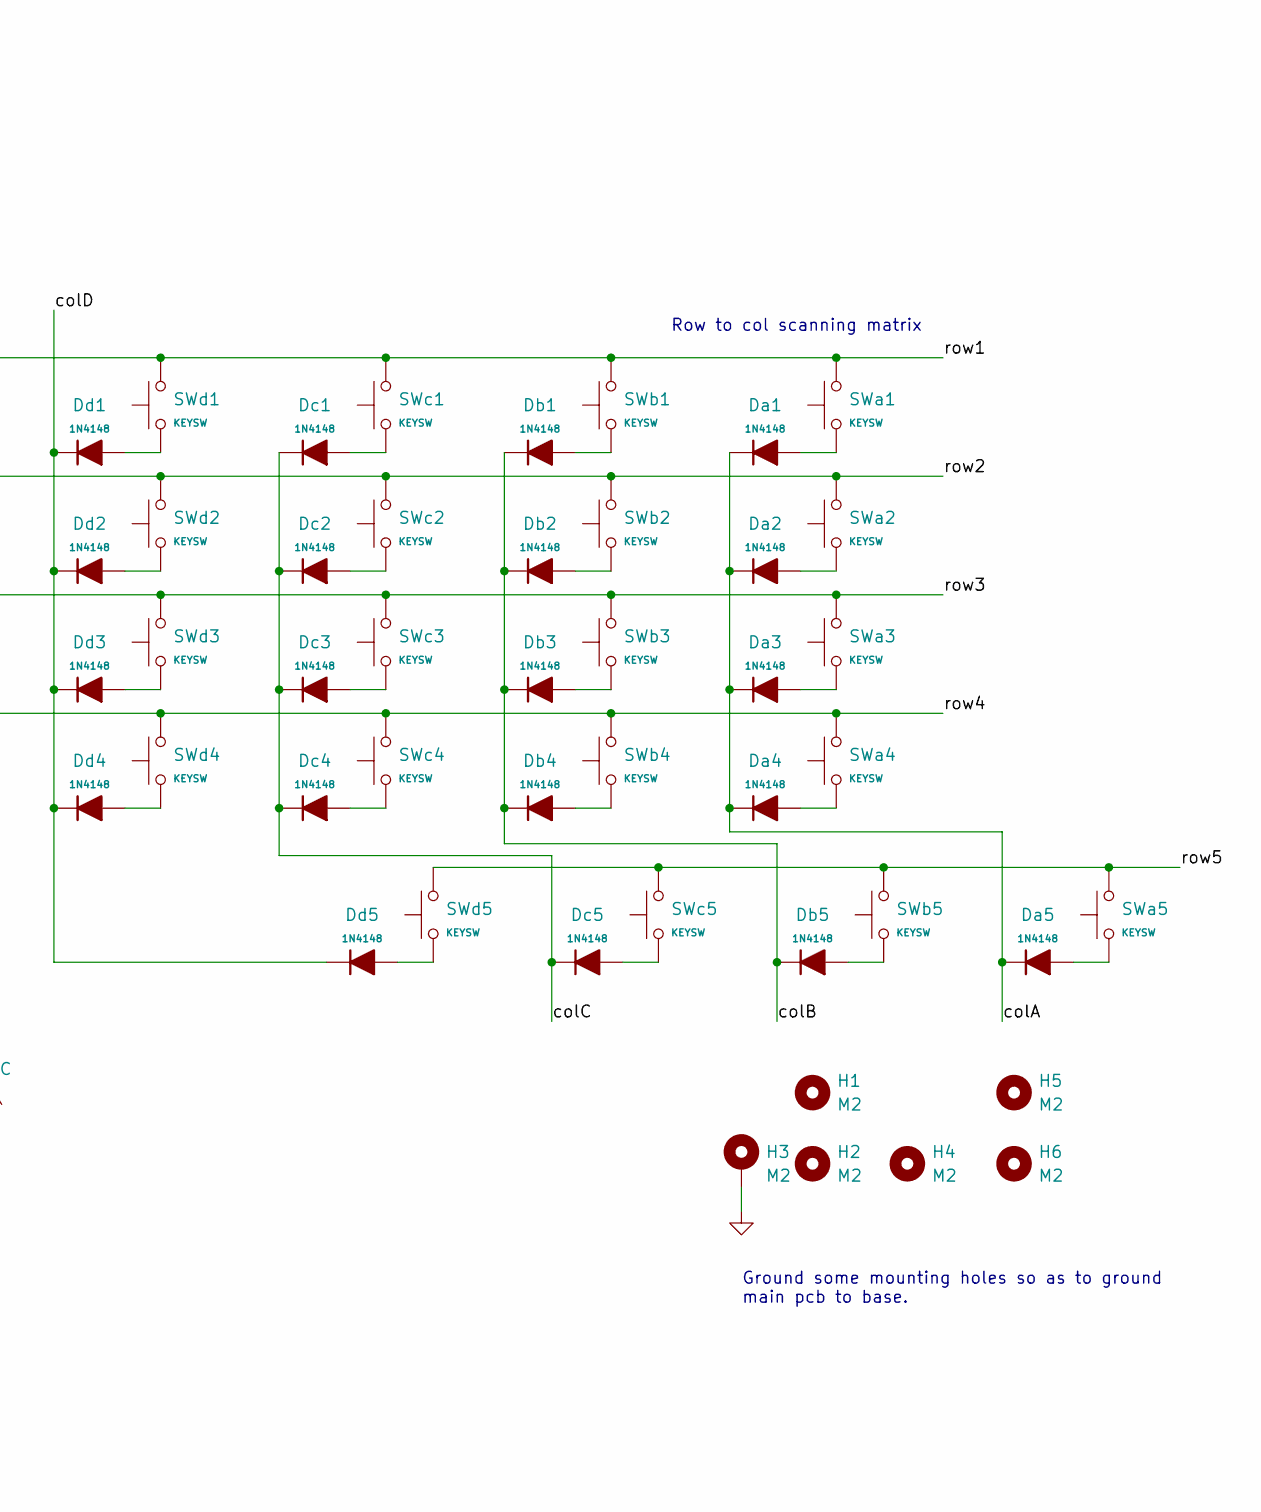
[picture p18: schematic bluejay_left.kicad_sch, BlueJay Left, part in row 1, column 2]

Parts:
C1, C2: 22p; C_Disc_D3.0mm_W1.6mm_P2.50mm
C3: 4.7u; CP_Radial_D4.0mm_P1.50mm
C4, C5: 100n; C_Disc_D4.3mm_W1.9mm_P5.00mm
DZ1, DZ2: 3.6V; D_DO-35_SOD27_P5.08mm_Horizontal
Da1, Da2, Da3, Da4, Da5: 1N4148; D_DO-35_SOD27_P5.08mm_Horizontal
Db1, Db2, Db3, Db4, Db5: 1N4148; D_DO-35_SOD27_P5.08mm_Horizontal
Dc1, Dc2, Dc3, Dc4, Dc5: 1N4148; D_DO-35_SOD27_P5.08mm_Horizontal
Dd1, Dd2, Dd3, Dd4, Dd5: 1N4148; D_DO-35_SOD27_P5.08mm_Horizontal
De1, De2, De3, De4: 1N4148; D_DO-35_SOD27_P5.08mm_Horizontal
Df2, Df3, Df4: 1N4148; D_DO-35_SOD27_P5.08mm_Horizontal
F1: 100mA; polyfuse_5.1mm
H1, H2, H3, H4, H5, H6: M2; MountingHole_2.2mm_M2_Pad
J1: SJ-43514; CUI_SJ-43514; PART_REV 1.04
PB1: RESET; SW_PUSH_6mm
PB2: BOOT; SW_PUSH_6mm
R1: 1.5k; R_Axial_DIN0204_L3.6mm_D1.6mm_P5.08mm_Horizontal
R2, R3: 75R; R_Axial_DIN0204_L3.6mm_D1.6mm_P5.08mm_Horizontal
R4: 10k; R_Axial_DIN0204_L3.6mm_D1.6mm_P5.08mm_Horizontal
SWa1, SWa2, SWa3, SWa4, SWa5: KEYSW; SW_Cherry_MX_PCB_1.00u
SWb1, SWb2, SWb3, SWb4, SWb5: KEYSW; SW_Cherry_MX_PCB_1.00u
SWc1, SWc2, SWc3, SWc4, SWc5: KEYSW; SW_Cherry_MX_PCB_1.00u
SWd1, SWd2, SWd3, SWd4, SWd5: KEYSW; SW_Cherry_MX_PCB_1.00u
SWe1, SWe2, SWe3, SWe4: KEYSW; SW_Cherry_MX_PCB_1.00u
SWf2, SWf3, SWf4: KEYSW; SW_Cherry_MX_PCB_1.00u
U1: ATmega328P-PU; DIP-28_W7.62mm_Socket
USB1: USB_B_Mini; USB_Mini_B_Female_548190519; MPN 0548190519; Digi-Key_PN WM17115-ND
Y1: 16MHz; Crystal_HC49-4H_Vertical

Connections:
/USBPRE_D+: DZ2.1 (K), R3.2, USB1.3 (D+)
/USBPRE_D-: DZ1.1 (K), R1.1, R2.2, USB1.2 (D-)
/USB_D+: R3.1, U1.4 (PD2)
/USB_D-: R2.1, U1.5 (PD3)
/colA: Da1.1 (K), Da2.1 (K), Da3.1 (K), Da4.1 (K), Da5.1 (K), U1.14 (PB0)
/colB: Db1.1 (K), Db2.1 (K), Db3.1 (K), Db4.1 (K), Db5.1 (K), U1.13 (PD7)
/colC: Dc1.1 (K), Dc2.1 (K), Dc3.1 (K), Dc4.1 (K), Dc5.1 (K), U1.26 (PC3)
/colD: Dd1.1 (K), Dd2.1 (K), Dd3.1 (K), Dd4.1 (K), Dd5.1 (K), U1.25 (PC2)
/colE: De1.1 (K), De2.1 (K), De3.1 (K), De4.1 (K), U1.24 (PC1)
/colF: Df2.1 (K), Df3.1 (K), Df4.1 (K), U1.23 (PC0)
/i2c_SCL: J1.3, U1.28 (PC5)
/i2c_SDA: J1.4, U1.27 (PC4)
/row1: PB2.1, SWa1.2, SWb1.2, SWc1.2, SWd1.2, SWe1.2, U1.2 (PD0)
/row2: SWa2.2, SWb2.2, SWc2.2, SWd2.2, SWe2.2, SWf2.2, U1.3 (PD1)
/row3: SWa3.2, SWb3.2, SWc3.2, SWd3.2, SWe3.2, SWf3.2, U1.15 (PB1)
/row4: SWa4.2, SWb4.2, SWc4.2, SWd4.2, SWe4.2, SWf4.2, U1.16 (PB2)
/row5: SWa5.2, SWb5.2, SWc5.2, SWd5.2, U1.17 (PB3)
GND: C1.2, C2.2, C3.2, C4.2, C5.2, DZ1.2 (A), DZ2.2 (A), H3.1, J1.1, PB1.2, PB2.2, U1.8 (GND), U1.22 (GND), USB1.5 (GND), USB1.SH (SHIELD)
unnamed: C1.1, U1.9 (XTAL1/PB6), Y1.2
unnamed: C2.1, U1.10 (XTAL2/PB7), Y1.1
unnamed: Da1.2 (A), SWa1.1
unnamed: Da2.2 (A), SWa2.1
unnamed: Da3.2 (A), SWa3.1
unnamed: Da4.2 (A), SWa4.1
unnamed: Da5.2 (A), SWa5.1
unnamed: Db1.2 (A), SWb1.1
unnamed: Db2.2 (A), SWb2.1
unnamed: Db3.2 (A), SWb3.1
unnamed: Db4.2 (A), SWb4.1
unnamed: Db5.2 (A), SWb5.1
unnamed: Dc1.2 (A), SWc1.1
unnamed: Dc2.2 (A), SWc2.1
unnamed: Dc3.2 (A), SWc3.1
unnamed: Dc4.2 (A), SWc4.1
unnamed: Dc5.2 (A), SWc5.1
unnamed: Dd1.2 (A), SWd1.1
unnamed: Dd2.2 (A), SWd2.1
unnamed: Dd3.2 (A), SWd3.1
unnamed: Dd4.2 (A), SWd4.1
unnamed: Dd5.2 (A), SWd5.1
unnamed: De1.2 (A), SWe1.1
unnamed: De2.2 (A), SWe2.1
unnamed: De3.2 (A), SWe3.1
unnamed: De4.2 (A), SWe4.1
unnamed: Df2.2 (A), SWf2.1
unnamed: Df3.2 (A), SWf3.1
unnamed: Df4.2 (A), SWf4.1
unnamed: F1.2, USB1.1 (VBUS)
unnamed: PB1.1, R4.2, U1.1 (~RESET/PC6)
VCC: C3.1, C4.1, C5.1, F1.1, J1.2, R1.2, R4.1, U1.7 (VCC), U1.20 (AVCC)

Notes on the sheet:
Low speed usb
Total bypass caps (both sides combined) = 9.7uF
TRRS jack
Row to col scanning matrix
Ground some mounting holes so as to ground main pcb to base.

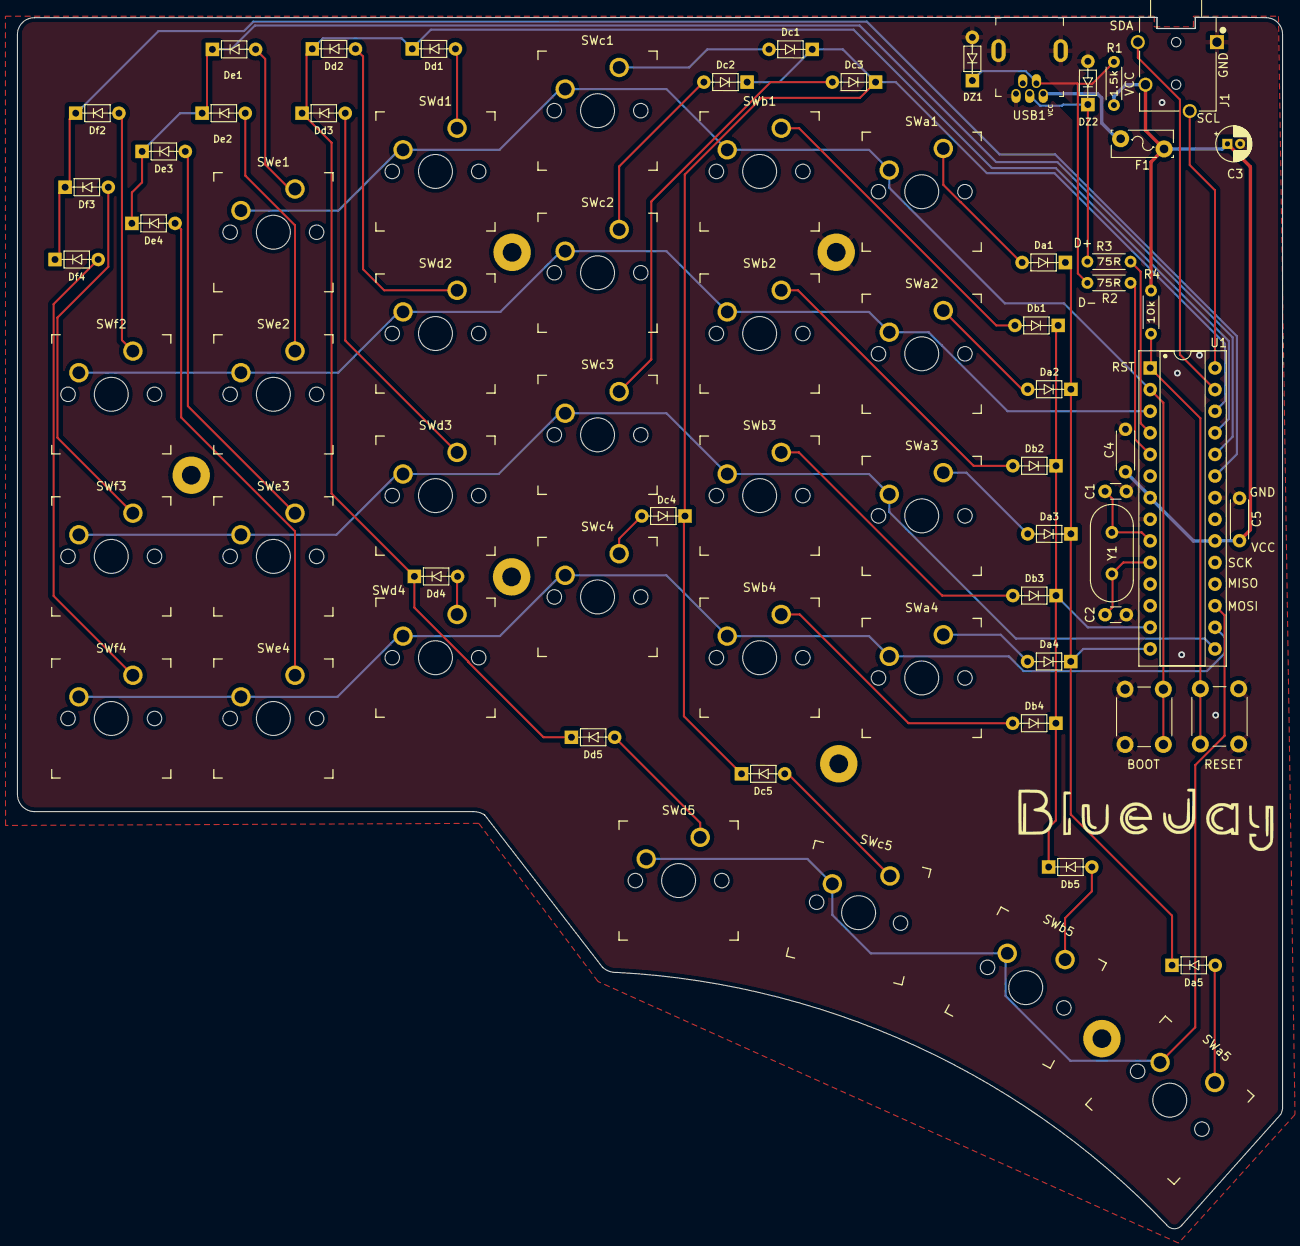
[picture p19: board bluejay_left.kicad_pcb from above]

Board: 2 copper layers, 148.7 x 142.4 mm, 79 parts (0 on the bottom side), 50 nets.

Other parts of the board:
Ref**: Val**; BlueJay in Halfomania font

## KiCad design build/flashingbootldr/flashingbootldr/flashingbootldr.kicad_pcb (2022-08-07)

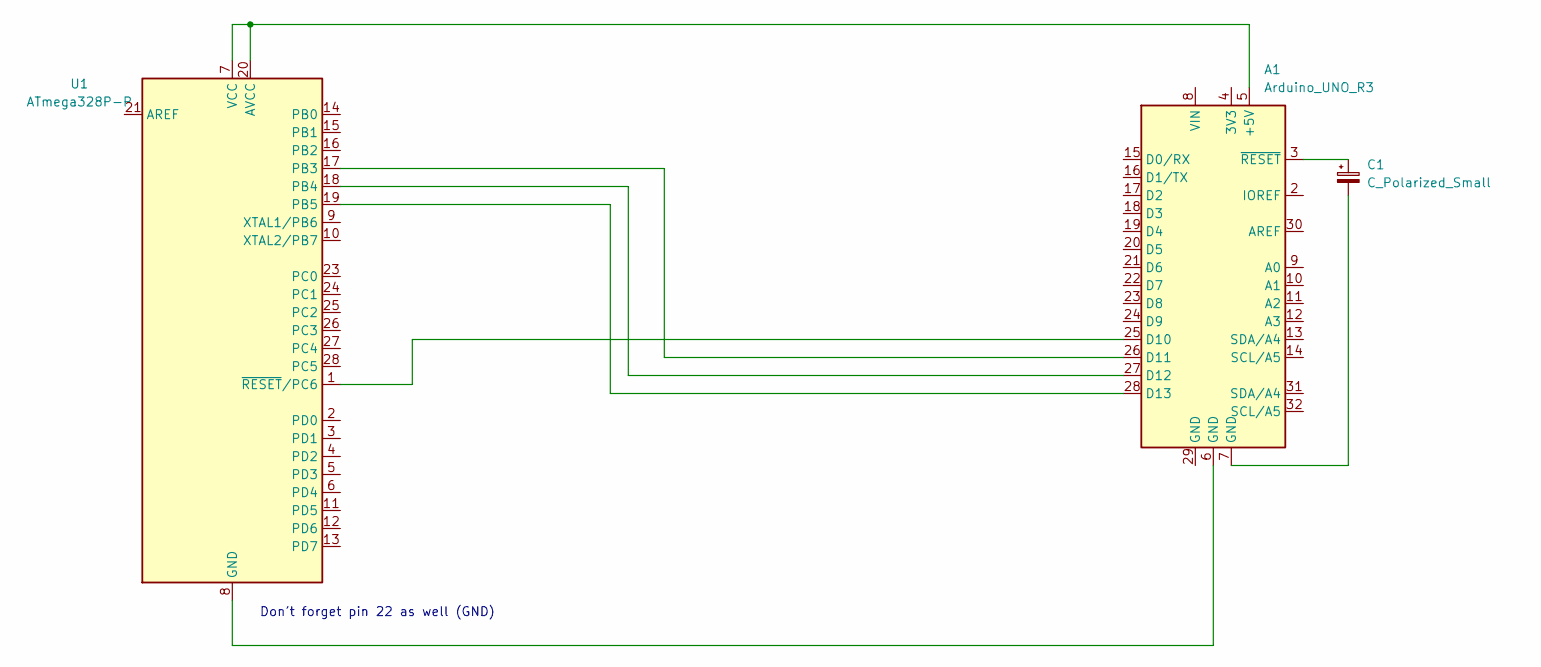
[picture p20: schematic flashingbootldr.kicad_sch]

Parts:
A1: Arduino_UNO_R3
C1: C_Polarized_Small; CP_Radial_D5.0mm_P2.50mm
U1: ATmega328P-P; DIP-28_W7.62mm

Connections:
unnamed: A1.3 (~RESET), C1.1
unnamed: A1.7 (GND), C1.2
unnamed: A1.26 (D11), U1.17 (PB3)
unnamed: A1.25 (D10), U1.1 (~RESET/PC6)
unnamed: A1.27 (D12), U1.18 (PB4)
unnamed: A1.28 (D13), U1.19 (PB5)
unnamed: A1.5 (+5V), U1.7 (VCC), U1.20 (AVCC)
unnamed: A1.6 (GND), U1.8 (GND), U1.22 (GND)

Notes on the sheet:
Don't forget pin 22 as well (GND)

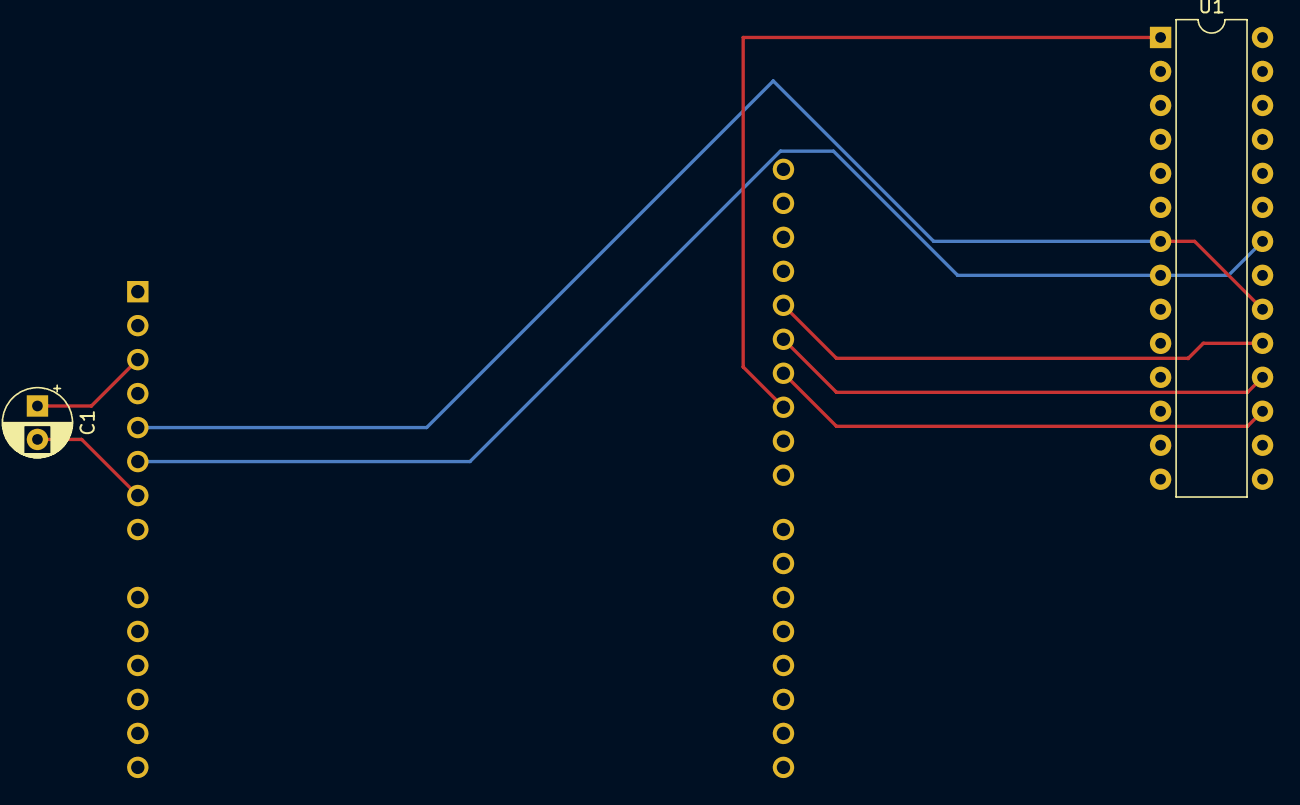
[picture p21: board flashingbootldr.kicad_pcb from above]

Board: 2 copper layers, 3 parts (1 on the bottom side), 8 nets.

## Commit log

2022-06-15 Prep work to start PCB design
    [bluejay_left.kicad_pcb, bluejay_left.kicad_sch]
2022-06-17 Some prep work done for PCB
    [bluejay_left.kicad_pcb, bluejay_left.kicad_sch]
2022-06-17 Start building left pcb
    [bluejay_left.kicad_sch]
2022-06-18 More work on left hand schematic
    [CUI_DEVICES_SJ-43514.igs, bluejay_left.kicad_sch]
2022-06-18 Further progress with left hand schematic
    [bluejay_left.kicad_pcb, bluejay_left.kicad_sch]
2022-06-19 Complete left hand schematic
    [bluejay_left.kicad_sch]
2022-06-19 Complete right hand schematic
    [bluejay_right.kicad_pcb, bluejay_right.kicad_sch]
2022-06-20 Further work on schematics
    [MF-R010.stp, bluejay_left.kicad_sch, usb mini b connector 54819-0519.stp]
2022-06-20 More work on schematics
    [bluejay_left.kicad_sch]
2022-06-20 Some updates to schematics before moving to pcb design
    [bluejay_right.kicad_sch]
2022-06-21 Work on PCBs
    [bluejay_left.kicad_pcb, bluejay_left.kicad_sch, bluejay_right.kicad_sch]
2022-06-21 Further work on pcbs
    [R_Axial_DIN0204_L3.6mm_D1.6mm_P5.08mm_Horizontal.step, bluejay_left.kicad_pcb]
2022-06-22 Further PCB updates
    [bluejay_left.kicad_pcb]
2022-06-28 Preliminary routing left hand pcb
    [bluejay_left.dsn, bluejay_left.kicad_pcb]
2022-06-28 Tweaks to component placements - left hand
    [bluejay_left.kicad_pcb]
2022-06-28 Further updates to pcb
    [bluejay_left.kicad_pcb]
2022-06-29 Updates to pcb design rules
    [bluejay_left.kicad_pcb]
2022-06-30 Tweak USB data lines
    [bluejay_left.kicad_pcb]
2022-06-30 Begin work on right pcb
    [bluejay_right.kicad_pcb, bluejay_right.kicad_sch]
2022-07-01 Routing of right PCB
    [bluejay_left.kicad_pcb, bluejay_right.dsn, bluejay_right.kicad_pcb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]
2022-07-02 Fine tune placement of switches - right hand
    [bluejay_right.kicad_pcb]
2022-07-03 Fine tune alignment of diodes and resistors
    [bluejay_left.kicad_pcb, bluejay_right.kicad_pcb]
2022-07-03 No need for decoupling cap on reset pin
    [bluejay_right.kicad_pcb, bluejay_right.kicad_sch]
2022-07-04 Add mounting holes
    [bluejay_left.kicad_pcb, bluejay_left.kicad_sch, bluejay_right.kicad_pcb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]
2022-07-06 Tweak placement of components on left hand
    [Bill of Material Summary.xlsx, bluejay_left.csv, bluejay_left.kicad_pcb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]
2022-07-10 Finish aligning switches, start work on plate
    [bluejay_right.kicad_pcb]
2022-07-11 Update Bill of Material Summary.xlsx
    [Bill of Material Summary.xlsx]
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2022-07-12 Ground a couple mounting holes so as to ground plate and base too
    [bluejay_left.kicad_pcb, bluejay_left.kicad_sch, bluejay_right.kicad_pcb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]
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2022-07-16 Test alternative component placement to see what happens
    [bluejay_left.dsn, bluejay_left.kicad_pcb, bluejay_left.kicad_sch]
2022-07-18 Alternative approach to place diodes
    [bluejay_left.kicad_pcb, bluejay_left.kicad_sch]
2022-07-19 Fine tune placement of diodes
    [bluejay_left.kicad_pcb]
2022-07-20 Complete alternative version of pcbs
    [bluejay_left.kicad_pcb, bluejay_right.dsn, bluejay_right.kicad_pcb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]
2022-07-21 Create base pcb
    [bluejay_base.dsn, bluejay_base.kicad_pcb, bluejay_base.kicad_sch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]
2022-07-22 add logo
    [bluejay_base.dsn, bluejay_base.kicad_pcb, bluejay_base.kicad_sch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]
2022-07-24 Fine tune pcbs
    [bluejay_base.kicad_pcb, bluejay_left.kicad_pcb, bluejay_left.kicad_sch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]
2022-07-26 Produce test gerber files
    [bluejay_base-B_Cu.gbr, bluejay_base-B_Mask.gbr, bluejay_base-B_Silkscreen.gbr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]
2022-07-28 Update schematics in preparation for review
    [bluejay_base.dsn, bluejay_base.kicad_pcb, bluejay_base.kicad_sch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]
2022-07-30 Fine tuning of schematics and pcbs in prep for review
    [bluejay_base.kicad_pcb, bluejay_base.kicad_sch, bluejay_left.kicad_pcb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]
2022-08-02 Update logo
    [bluejay_base.kicad_pcb, bluejay_left.kicad_pcb, bluejay_right.kicad_pcb]
2022-08-04 Produce some printouts for review
    [bluejay_left.dsn, bluejay_left.kicad_pcb, bluejay_left.kicad_sch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]
2022-08-07 Diagram for flashing of bootloader
    [flashingbootldr.kicad_pcb, flashingbootldr.kicad_sch]
2022-08-14 remove mounting hole 9
    [bluejay_base.kicad_pcb, bluejay_base.kicad_sch, bluejay_left.kicad_pcb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]
2022-08-15 Round edges of PCB
    [bluejay_base.kicad_pcb, bluejay_left.kicad_pcb, bluejay_plate.kicad_pcb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]
2022-08-25 tweak board edges
    [bluejay_left.kicad_pcb]
2022-09-01 fine tune edge cuts
    [bluejay_left.kicad_pcb]
2022-09-04 Fine tuning of edge cut for plate
    [bluejay_plate.kicad_pcb]
2022-09-10 Update placement of some components and size of drill holes
    [bluejay_base.kicad_pcb, bluejay_base.kicad_sch, bluejay_left.kicad_pcb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]
2022-09-13 update bootloader flashing instructions
    [flashingbootldr.kicad_sch]
2022-09-14 Fine tune edge cut
    [bluejay_base.kicad_pcb, bluejay_left.kicad_pcb, bluejay_plate.kicad_pcb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]
2022-09-14 Further work on plate
    [bluejay_plate.kicad_pcb]
2022-10-14 Update gerber files
    [bluejay_base-B_Cu.gbl, bluejay_base-B_Cu.gbr, bluejay_base-B_Mask.gbr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]
2022-10-17 simple corrections in prep for rev 1.1
    [bluejay_left.kicad_pcb, bluejay_plate.kicad_pcb]
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2023-06-16 fix routing with usb connector
    [bluejay_left.kicad_pcb, bluejay_left.kicad_sch]

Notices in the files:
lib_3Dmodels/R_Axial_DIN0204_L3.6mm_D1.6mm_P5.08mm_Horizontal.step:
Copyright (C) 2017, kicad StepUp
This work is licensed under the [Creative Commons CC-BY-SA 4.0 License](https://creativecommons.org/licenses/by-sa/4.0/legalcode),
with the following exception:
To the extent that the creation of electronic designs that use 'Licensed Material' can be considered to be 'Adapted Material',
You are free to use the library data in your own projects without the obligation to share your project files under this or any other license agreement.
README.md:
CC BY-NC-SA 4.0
